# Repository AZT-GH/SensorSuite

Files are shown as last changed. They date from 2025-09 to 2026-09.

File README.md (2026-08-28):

# AZSensorSuite




> [!WARNING]
> This device has been mostly tested, however, problems may arise. Expect changes and please report any inaccuracies or issues.

## Overview
land_export
   
AZSensorSuite (AZSS) is an ultra-low-power, data-acquisition hardware platform designed to be user-programmed for a variety of applications. 

The included example firmware implements a unidirectional object counter and temperature and humidity logger, with BLE implemented for real time updates and data download.

**Interactive Viewer:** View the PCB and schematic entirely in your browser on [KiCanvas](https://kicanvas.org/?repo=https%3A%2F%2Fgithub.com%2FAZT-GH%2FSensorSuite%2Ftree%2Fmain%2Fhardware).

#

**Special thanks to [**PCBWay**](https://www.pcbway.com/) for sponsoring the development of this project.** 

If you're looking for high-quality advanced PCB manufacturing and assembly and great customer support, check them out.

#

### Hardware Features

* **SoC / Connectivity:** Nordic NRF54L15 (via U-Blox Nora B206 module). Supports BLE 6.0, Matter, Thread, Zigbee, and proprietary 2.4GHz communication.
* **ToF Sensor:** ST Microelectronics VL53L4CD. Used for ULP presence detection ([STSW-IMG034](https://www.st.com/en/embedded-software/stsw-img034.html), as low as 154µW) or standard ranging ([STSW-IMG026](https://www.st.com/en/embedded-software/stsw-img026.html)).
* **Environmental Sensor:** Sensirion SHT30 for ambient temperature and humidity readings.
* **Power:** Powered by a CR2032 coin cell, converted to 2.8V. The entire system is ultra-low power (e.g., ~400µA in the human detection example).

> [!TIP]
> The VL53L4CD and SHT30 are both members of pin-compatible sensor families. They can easily be replaced to meet specific project requirements or to navigate supply chain shortages.

## Example Quickstart Guide

### Requirements
* NRF54L15DK (highly recommended) or another SWD debugger.
* SensorSuite PCB and TC2030-IDC-NL cable.
    * *Alternatively:* NRF54L15DK with sensor breakouts.
* [nRF Connect SDK v3.1.1](https://developer.nordicsemi.com/nRF_Connect_SDK/doc/latest/nrf/index.html) via nRF Connect for VS Code.
* Python 3.7 or higher.

### Build and Flash Process
* If working with the development kit, skip step 5 and in `firmware/prj.conf` set `CONFIG_APP_BOARD_IS_PROD=n`.
1.  Clone the repository to a path that contains **no spaces** (e.g., `/projects/sensor_suite` is good; `/projects/sensor suite/` will cause build errors).
2.  Open the application in nRF Connect and navigate to the `firmware` subfolder.
3.  Create a new build configuration:
    * **Target:** `nrf54l15dk/nrf54l15/cpuapp/ns`
    * **Base configuration:** `prj.conf`
    * **Base devicetree overlay:** `boards/nrf54l15dk_nrf54l15_cpuapp_ns.overlay`
    * Select your desired build optimization.
4.  Click **Generate and Build**.
5.  Connect the TC2030-IDC-NL to the DK. The DK will automatically detect it and change the target to the connected custom PCB.
6.  Press **Flash and Erase**. (You may flash without erase after the first flash)
* If a module is being flashed for the first time, it may have memory protections enabled. Click `Yes` in the pop-up to allow recovery.

error

## PCB Ordering Guide

| I used [**PCBWay**](https://www.pcbway.com/) for PCB fabrication as they offer reliable quality, competitive pricing, and quick turnaround, even with the nonstandard specs required by this project. |
|---|
### 1. Clone and Open the Project
1. Clone the repository to your local machine.
2. Open `azss.kicad_pro` in **KiCad 9** or newer.
3. *(Optional)* Make any custom modifications needed for your project.

### 2. Run Design Rules Check (DRC)
Run the DRC in KiCad to verify your layout.

> [!NOTE]
> You can safely ignore the following DRC error:
> 
> KiCad DRC Error

### 3. Export Gerber & Drill Files
1. Open the PCB Editor.
2. Go to **File → Fabrication Outputs → Gerbers (.gbr)**.
3. Choose or create a dedicated output directory (e.g., `fabrication/`).
4. Click **Plot**.
5. Click **Generate Drill Files**, keep default options, and click **Generate**.
6. Compress the contents of your output directory into a single **`.zip`** file.

### 4. Upload to PCBWay
1. Go to the [PCBWay Quick Order Page](https://www.pcbway.com/QuickOrderOnline.aspx).
2. Upload your `.zip` file.
3. Inspect your layout using the online **Gerber Viewer** to verify the gerber exported correctly.

### 5. Configure PCB Parameters
Set the board parameters to match the project requirements:

* **Layers:** Select **4 Layers**.

<details>
<summary><b>Click to view 4-Layer Stackup Configuration</b></summary>
<br>
Layer Stackup Configuration

</details>

* **Required PCB Specifications:**
  * **Min Track / Spacing:** `4/4mil`
  * **Min Hole Size:** `0.3mm`
  * **Surface Finish:** `Immersion Gold (ENIG)`
  * **Via Process:** `Plugged vias with solder mask`

### 6. Add Assembly / Stencil & Checkout
1. **Stencil / Assembly:** Add an **SMD Stencil** if hand-assembling, or select PCBWay's **Assembly Service** if you want them professionally assembled.
2. Click **Save to Cart**.
3. Wait for PCBWay's order review to complete, typically within an hour.
4. Proceed to checkout, pay, and wait for your boards!
   
## Release Notes

v1.0.0 - 17/04/26 - Initial release with all core features implemented

## License

Copyright © 2026 Adam Zembrzuski. 

This project is licensed under the TAPR Open Hardware License ([www.tapr.org/OHL](https://www.tapr.org/OHL)).

A full copy of the license is available in the `license.txt` file in this repository.

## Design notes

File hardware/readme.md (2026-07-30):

## Hardware

This folder contains all hardware design files and documentation.

**Interactive Viewer:** View the PCB and schematic entirely in your browser on [KiCanvas](https://kicanvas.org/?repo=https%3A%2F%2Fgithub.com%2FAZT-GH%2FSensorSuite%2Ftree%2Fmain%2Fhardware).
##
### PCB Fabrication

Special thanks to [**PCBWay**](https://www.pcbway.com/) for sponsoring the development of this project.

| Parameter | Value |
|---|---|
| Layers | 4 |
| Board thickness | 1.6mm |
| Surface finish | 2µ" ENIG with *(preferably)* selective hardened gold for the battery contact |
| Min hole size | 0.3mm |
| Min track spacing | 4mils |
| Via process | See below |

- Due to the nature of the vias sitting on the battery contact, copper/resin filled vias are highly encouraged.

- LPI filled or tented vias will work for at least ~50 insertions.

- **Untented vias are unsuitable and will cause catastrophic failure if a battery is inserted.**

### Stencil

Electropolished stencils are preferred over 
laser-cut for cleaner paste release on the LGA pads of the Nora B206.

### Assembly Notes

- The U-Blox Nora B206 and ST VL53L4CD are LGA components and **must be reflow soldered**. 
  Hand soldering is not possible.

### Schematic Notes

- **R1** should be replaced to a suitable value for current measurement instead of 0 ohms.
- Several components are marked DNP. These should only be populated if you have a specific reason to do so.

> [!TIP]
> If the SHT3x is not required, C11 and U4 can be DNP'd, and in the example firmware, `CONFIG_APP_SHT_ENABLE` should be set to `n`in `firmware/prj.conf`.

### Test Points

Test point layout is visible below and is consistent with the schematic.

test points

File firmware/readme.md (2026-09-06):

## Firmware

This folder contains all firmware source files and documentation. The latest firmware (release v1.0.0)
has been verified working on PCB V1.12 (all functions).

For build and flash instructions, see the 
[main README](../README.md#example-quickstart-guide).
##

### Implementation Status

| Feature | Status |
|---|---|
| VL53L4CD ToF detection | Complete |
| SHT30 temperature / humidity | Complete |
| BLE service | Largely complete |
| NVM storage | Complete |
| Dynamic ToF interval | Complete |
| SAADC VCC monitoring | Planned |

### BLE Service

The device exposes a custom BLE service with the following characteristics:

Service UUID : `229a0001-ad33-4a06-9bce-c34201743655`

| Characteristic | UUID | Properties | Encryption | Description |
|---|---|---|---|---|
| Count | `229a0002-ad33-4a06-9bce-c34201743655` | Notify, Read | None | Returns detected object count |
| Temperature | `229a0003-ad33-4a06-9bce-c34201743655` | Notify, Read | None | Returns last good temperature |
| Humidity | `229a0004-ad33-4a06-9bce-c34201743655` | Notify, Read | None | Returns last good humidity |
| Bulk Download | `229a0005-ad33-4a06-9bce-c34201743655` | Notify | Level 2 | Used to download timestamp log |
| Current Timestamp | `229a0006-ad33-4a06-9bce-c34201743655` | Read | None | Returns current timestamp |
| Base Timestamp | `229a0007-ad33-4a06-9bce-c34201743655` | Write, Read | Level 2 | Used to write base timestamp |
| Command | `229a0008-ad33-4a06-9bce-c34201743655` | Write, Read | Level 2 | Used to call one of many commands |

### 'Command' Commands

| Command | Hex | Return | Description |
|---|---|---|---|
| Connection Interval 20ms | `0x00` | none | Sets new connection interval |
| Connection Interval 100ms | `0x01` | none | Sets new connection interval |
| Connection Interval 512ms | `0x02` | none | Sets new connection interval |
| Connection Interval 1024ms | `0x03` | none | Sets new connection interval |
| Download Start | `0x10` | 0 on success | Starts timestamp download notifications |
| Download Stop | `0x11` | 0 on success | Stops timestamp download notifications |
| Storage Clear | `0x13` | 0 on success | Clears NVM, including bonding, configuration, and logs |
| Firmware Version | `0x20` |int (eg `12` for V1.2)| Returns FW Version |
| Active Period 08-16 | `0x30` |  0 on success | Sets the device to only detect <sup>¶</sup> between 08:00 and 16:00 |
| Active Period 08-18 | `0x31` |  0 on success | Sets the device to only detect between 08:00 and 18:00 |
| Active Period 09-21 | `0x32` |  0 on success | Sets the device to only detect between 09:00 and 21:00 |
| Active Period 00-24 | `0x33` | 0 on success | Sets the device to detect irrespective of time (not date) |
| Inactive Weekend | `0x34` | 0 on success | Sets the device to not detect during the weekend |
| Active Weekend | `0x35` | 0 on success | Sets the device to detect during the weekend |

*¶ Detect refers to human/object detection, ambient detection is still carried out*

### Data Collection
The device only collects timestamp logs if it is within the active period, definable via the 0x3- commands. The selected active period is stored in NVM.

Ambient logs are collected regardless of the system state (if the SHT3x is enabled in `prj.conf`).

### Logging

*Logging described in this section is independent of sensor logging*

RTT logging is enableable in `prj.conf`. Connect via the nRF Connect for Desktop 
terminal or a J-Link RTT Viewer.

### Kconfig Options
All Kconfig options can be adjusted in `firmware/prj.conf`. If changes are not being applied, ensure `prj.conf` is included in the build config.

#### System Level
<details>
<summary>For lowest current consumption disable all logging, this will reduce current consumption by roughly 200μA</summary>

```
CONFIG_USE_SEGGER_RTT=n
CONFIG_SERIAL=n

CONFIG_LOG=n
CONFIG_LOG_BACKEND_RTT=n
CONFIG_LOG_BACKEND_UART=n

CONFIG_PRINTK=n
CONFIG_BOOT_BANNER=n

CONFIG_UART_CONSOLE=n
CONFIG_RTT_CONSOLE=n
```

</details>
<details>
<summary>Bluetooth options such as device name and default connection interval are available to be defined statically.</summary>
  
```
CONFIG_BT_DEVICE_NAME="AZSensorSuite-001"
```
</details>

#### Application Level

Application specific Kconfig option descriptions can be viewed in the visual kconfig editor, in the nRF  Connect SDK. Below are some key options.

- `CONFIG_APP_VL53_DETECTION_INTERVAL_MS` - Inter-measurement period for the VL53L4CD ToF sensor in milliseconds. Must be a multiple of ten.

- `CONFIG_APP_CONSEC_DETECT_FILTER` - Require multiple consecutive detections before logging an event. Should be paired with a lowered detection interval.

- `CONFIG_APP_SHT_ENABLE` - Disable functions related to the SHT3x, notably it still *remains powered* even in this mode.

- `CONFIG_APP_LOG_FULL_STRATEGY` - Determines if logs are overwritten when full or if writing stops.

- `CONFIG_APP_BOARD_IS_PROD` - Should be set to `n` if building for the nRF5454L15-DK.

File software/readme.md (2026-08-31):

## Software

This folder contains the host-side Python client for communicating with
AZSensorSuite over BLE.

**ML functionality has not been implemented yet, and will not be implemented in the forseeable future.**

> [!WARNING]
> This client was written quickly to test the firmware and is due for a rewrite. Please expect and report bugs.

*Python 3.7 or higher is required.*

##

### Overview

The intended data flow is:
```
Device (BLE) → azss_client.py → csvs/ → azss_train.py → model → azss_infer.py → prediction
```

The BLE client is currently implemented. Model training and infer scripts 
are in progress.

## azss_client.py
### Setup
```bash
pip install -r requirements.txt
```

> [!NOTE]
> On macOS, Bleak exposes CoreBluetooth UUIDs rather than MAC addresses. 
> When prompted for a Bluetooth address, use the UUID string instead.

### Usage
```bash
python azss_client.py
```

The client runs as an interactive shell. Type `help` for a list of commands 
or `exit` to quit.

### Commands

| Command | Requires Connection | Description |
|---|---|---|
| `scan` | No | Scan for nearby BLE devices |
| `connect` | No | Connect to a device by Bluetooth address |
| `disconnect` | No | Disconnect from the current device |
| `unpair` | No | Unpair the current device |
| `read uuid` | Yes | Read a characteristic by UUID |
| `read count` | Yes | Read detected object count since last initialisation |
| `read temp` | Yes | Read temperature (returns °C, °F, and K) |
| `read humidity` | Yes | Read relative humidity |
| `read time` | Yes | Read the current device timestamp in milliseconds |
| `write` | Yes | Send a raw hex command byte to the Command characteristic |
| `write time` | Yes | Sync device base timestamp to system time |
| `write time custom` | Yes | Write a custom base timestamp in milliseconds |
| `download` | Yes | Download the full timestamp and ambient log |

### Download Output

Data is written to the `csvs/` folder, created automatically if it does not exist.

**`stamps.csv`** — ToF event log

| Column | Description |
|---|---|
| `row` | Row index |
| `seq` | BLE packet sequence number |
| `delta_i32` | Time delta from previous event in seconds |
| `cumulative_i64` | Cumulative elapsed seconds since base timestamp |
| `real_i64` | Absolute Unix timestamp in seconds |

**`ambient.csv`** — Temperature and humidity log (sampled every 15 minutes)

| Column | Description |
|---|---|
| `row` | Row index |
| `seq` | BLE packet sequence number |
| `temp_i8` | Temperature in °C |
| `humidity_u8` | Relative humidity as a percentage |
| `real_i64` | Absolute Unix timestamp in seconds |

## azss_train.py

## azss_infer.py

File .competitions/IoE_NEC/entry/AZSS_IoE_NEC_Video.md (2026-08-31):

# Demo Video

[Watch on YouTube](https://www.youtube.com/watch?v=mV7OCPhzP5s)

thumbnail

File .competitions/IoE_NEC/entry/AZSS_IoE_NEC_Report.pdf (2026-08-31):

## An Ultra-Low-Power IoT ToF Sensor Node

Adam Zembrzuski, Banbridge Academy, Banbridge, Down, BT32 4AQ

### 1 - Introduction

My GCSE Technology project was a bin-mounted object counter, built around an IR LED, photodiode and 9V battery. It worked but the prototype was fragile, bulky and power-hungry, unsuitable for commercial production. This project is the result of wanting to develop the concept properly. An almost product-grade redesign that also served as my foundation to learning a modern Bluetooth SoC platform. The project was primarily funded by my Arkwright Scholarship, with PCB manufacturing sponsored by PCBWay. Development began in August 2025, with v1.0 releasing during April 2026.

The project is called AZ Sensor Suite (AZSS).

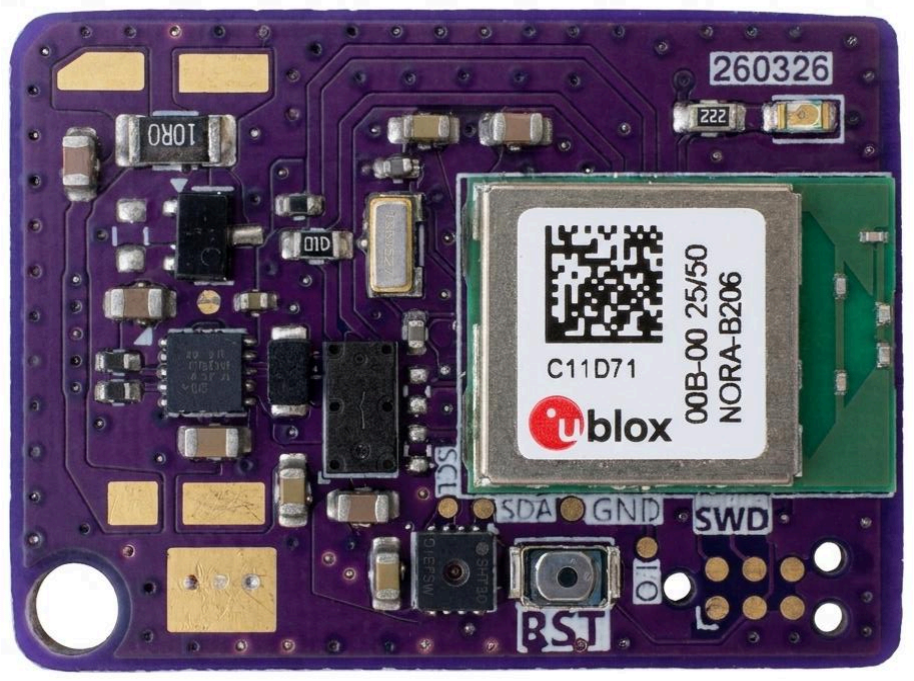
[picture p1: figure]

Fig 1.0.0.1 - Assembled PCB v1.11 (30.2 x 22.1 mm)

### 2 - The Problem to be Solved

There does not exist a low cost (Spec 2.1), small form factor (Spec 2.2), ultra-low power (Spec 2.3) , IoT enabled (Spec 2.4), unified development platform for distance-measurement and presence detection applications. This means it is difficult to leverage ToF sensing in heavily constrained environments.

Example applications include:

- Fill-level monitoring for storage containers
- Presence-triggered network input (e.g., for smart home automation)
- Unidirectional throughput and object counting
- Simple tamper detection

The device should operate autonomously via direct wireless connectivity or be able to integrate into broader smart-home or industrial networks (Spec 2.5), and should be highly accurate (Spec 2.6) so that obtained data is reliable and usable for analysis.

Paper produced for the Institution of Electronics

### 3 - Research

3.1 - Customer-base and usage model
The project is primarily an open-hardware platform, with user responsibility for their own application firmware. To improve ease of development, a reference firmware implementation is provided for unidirectional object counting with Bluetooth connectivity.

The project caters to two market segments

- Conventional purchase model - The user programs the device independently. These users retain total control over the project. They prioritise reliability, repairability and ease of programming. (Spec 3.1)
- Hardware-as-a-Service (HaaS) model - The user receives a turnkey solution that does not require custom firmware development. Under this rental model, the user does not have to manage installation and maintenance, over a typical two-year lifecycle. (Spec 3.2)

This report will focus on users that fall under the conventional purchase model.

3.2 - Market solutions
As established in the problem analysis, no commercial solutions currently address this specific niche. The closest market analogues are official sensor evaluation breakout boards. While these manufacturer-provided modules break out the Time-of-Flight (ToF) sensor pins for initial firmware validation, they carry significant limitations for deployment:
- Lack of integration - They only feature the sensor, essential passives and a pin header. They lack onboard processing, power management, or wireless connectivity.
- Poor form factor - They require external processors to be connected via jumper wires, making them bulky and structurally unsuitable for permanent and/or mobile applications.
- High unit cost - They are produced in low volumes for development purposes, hence have a premium cost. A single breakout board costs more than the total BoM cost of the AZSS.

Breakout boards were used extensively during the initial phases of this project to validate firmware and characterise the sensor. However, this development process highlighted their limitations; the resulting breadboard setups were highly fragile, expensive, and unsuitable for any deployment.

3.3 - Hardware research

3.3.1 - Power Source and Topology

To maximise its deployability, the project requires an ultra small form factor, which implies an ultra-low-power budget. A primary CR2032 coin cell was selected over secondary lithium alternatives due to widespread availability and the elimination of space-demanding charging circuitry.

A CR2032 cell features a nominal voltage of 3.0 V with a usable range of roughly 2.0 V to 3.2 V. Due to the system's target operating voltage being 2.8 V, a buck-boost topology was required to efficiently utilise the full voltage range. The TI TPS63900 was chosen as a buck-boost converter with low quiescent current of 75 nA and high theoretical efficiency of approximately 88% under coin cell power.

Adam Zembrzuski, Banbridge Academy, Banbridge | Page 2

3.3.2 - Distance Sensing Technology

Two ToF technologies were evaluated:

Selection Criteria | Infrared (IR) Laser ToF | Ultrasonic ToF
Key Advantages | ● Low cost ● Simple API integration ● Narrow FoV without optics | ● Lower active current draw ● Optical material agnosticity ● Higher sampling rate
Key Limitations | ● Higher current draw ● Lower maximum operating range | ● High component cost ● Requires mechanical horn to narrow FoV

Fig 3.3.2.1 -
Comparison of infrared and ultrasonic ToF sensing

IR laser sensing was selected to minimise hardware complexity and cost per unit. Specifically, the STMicroelectronics VL53L4CD was chosen as it includes an autonomous, ultra-low-power presence detection API that reduces current consumption to as little as 55 μA [1], and operates on a relatively low supply voltage of 2.8 V.

3.3.3 - System on Chip (SoC) Selection

The core SoC architecture requires capabilities to use a wireless protocol capable of integrating with smart-home networks without exceeding the strict power budget imposed by a coin cell. Wi-Fi connectivity was ruled out immediately due to its high peak current, which would rapidly deplete or brown out a CR2032 cell. Consequently, low-power personal wireless area network (LP-WPAN) protocols, specifically Bluetooth Low Energy (BLE), Thread, and Zigbee, were identified as viable IoT protocols for home and network integration.

To fulfil these requirements, the Nordic Semiconductor nRF54L15 was selected. As a state of the art SoC manufactured on TSMC’s 22ULL (22 nm, ultra low leakage) process node, it delivers double the processing performance and triple the energy efficiency of previous generation hardware. It supports multi-protocol stacks, features an ultra low sleep current (as low as 0.7 μA [2]), and offers a robust SDK ecosystem, with free training material provided by Nordic Semiconductor.

Crucially, its operating voltage matches the sensor rail, enabling the entire system to run off a single power supply and eliminating the space, cost, and efficiency losses of logic-level translation. I decided to use an FCC/CE-certified module over a bare SoC as it integrated the antenna and other essential passives.

This minimised RF layout complexity and greatly reduces RF certification costs if the device is to be commercially manufactured. The benefit of already having certain core passives also reduces the total number of unique parts in the BoM. However the limitations of this are that the total cost for a module is higher than the cost of the bare SoC and passives, and that a smaller solution footprint can be designed if a module is not used.

3.3.4 - Auxiliary Sensor Selection

To add environmental telemetry, a low-power, low-cost Sensirion SHT30 temperature and humidity sensor was integrated onto a shared I

2C bus. Importantly, both the VL53L4CD and the SHT30 share pin-compatible footprints with other sensors in their respective manufacturer portfolios. This design choice allows the platform's hardware configuration to be modified for alternative use cases (e.g., extended ranging depth or temperature accuracy) purely via a component swap and a firmware update, without requiring a PCB redesign.

3.4 - Firmware research

3.4.1 - Operating System Selection

To match the requirements of sensor monitoring and multi-protocol wireless communication, a real-time operating system (RTOS) was chosen over a traditional bare-metal super-loop architecture. While a bare metal approach minimises overhead, executing network tasks alongside sensor interactions and NVM events introduces timing risks and blocking conditions.

Zephyr RTOS was chosen as the firmware platform as it features industry-grade networking stacks that are natively supported by nRF Connect SDK in the VS Code IDE. Zephyr is the standard for firmware for Nordic Semiconductor based processors hence there is a wealth of examples available for users to adapt for their application firmware.

3.4.2 - Sensor API and Power Architecture

The implementation required selecting from one of two manufacturer-provided APIs for the VL53L4CD sensor.

- STSW-IMG026 (Ranging Driver) - Provides comprehensive distance data over an I

2C bus.
Relies on processor polling, which prevents the processor from entering low-power sleep states for extended periods, leading to increased baseline current consumption.
- STSW-IMG034 (Presence Driver) - Functions autonomously by executing threshold checks directly on the sensor. Operates on an interrupt-driven basis, asserting a hardware interrupt pin only when a target crosses a configured detection threshold. An I

2C write is still required to deassert the interrupt pin.

To maximise battery longevity, the STSW-IMG034 API was selected. This choice permitted a highly efficient, event-driven firmware architecture. The nRF54L15 remains in an ultra-low-power "System ON" sleep state, consuming 2.9 μA of current (more than the 0.7 μA floor due to full memory retention), and only wakes to process data when triggered by the sensor's hardware interrupt.

3.5 - Reference Firmware and Development Methodology

3.5.1 - Reference Firmware Architecture

To demonstrate the platform's capabilities and provide a foundation for custom development, a reference firmware implementation was developed for unidirectional object counting with environmental logging.

The application utilises an event-driven architecture to capture, queue and secure data:

- Autonomous Presence Interrupts - The VL53L4CD is configured using the STSW-IMG034 API, allowing the nRF54L15 to remain in ultra-low-power ‘System ON’ sleep state and wake up solely to process events or perform periodic logging (if configured).
- Buffered Storage Architecture - To ensure data persistence across power faults, events are queued in a RAM ring buffer and flushed to a 400 KB NVM partition periodically. Storing events as 32-bit timestamps, providing a theoretical capacity of over 50,000 entries (the timestamps are not strictly 32-bit due to filesystem overhead). Because the nRF54L15 utilises Resistive RAM (RRAM) for NVM, wear levelling is not necessary.
- Periodic Environmental Telemetry - The SHT30 temperature and humidity sensor is managed via a low-frequency polling schedule on the shared I

2C bus. Its logs are directly committed to the NVM.

This reference design serves as a functional validation example that showcases all of the primary hardware subsystems, including the BLE stack, NVM storage, I

2C bus, and low-power hardware interrupts under realistic constraints.

3.5.2 - Hardware / Firmware Co-design Methodology

To minimise project schedule risks and ensure rapid hardware bring-up, a hardware/software co-design methodology was employed. Firmware development was decoupled from physical PCB fabrication by implementing the firmware concurrently on an off-the-shelf Nordic Semiconductor development kit (DK). The development kit contains a SEGGER J-Link OB debugger that programs the nRF54L15 SoC on the DK and can be connected by a cable to program a custom PCB. It also supports breakpoint debugging allowing for thread activity and stack usage to be analysed.

This parallel workflow allowed the BLE stack, low-power state transitions, and sensor drivers to be fully validated and debugged in advance. Consequently, when the PCB prototype was assembled, a usable firmware version could be almost immediately flashed, reducing integration debugging to hardware-specific routing and definitions.

### 4 - Design and Build

4.1 - Schematic Design
Unlike the physical PCB layout stage, where Electronic Design Automation software actively flags issues, the schematic entry phase relies entirely on manual design verification. Any electrical routing or footprint mapping errors introduced here are silent and pass automated checks unnoticed.

This risk materialised during the initial design cycle: a schematic symbol adapted for the PMOS-based reverse polarity protection circuit featured non-standard pin numbering that did not match its physical footprint, resulting in a complete power delivery failure on the prototype. This highlighted the necessity of rigorous, multi-point footprint verification prior to fabrication. The development of the schematic proceeded through several distinct stages:

4.1.1 - Power Delivery and Diagnostics

The primary power stage was modelled using Texas Instruments’ WEBENCH suite as an initial baseline. To elevate this reference design for custom debugging and Design for Testability (DFT), several additions were integrated as illustrated in Fig 4.1.1.1.

- A PMOS-based reverse polarity protection circuit to safeguard the board during battery swapping.
- A series shunt resistor for optional, high-precision power measurements.
- Dedicated diagnostic test points for the battery voltage (+BATT), system voltage (+2V8), ground (GND), and the shunt’s high/low nodes.
- Zero-ohm current limit configuration resistor (instead of a direct connection to ground) to allow adjustment of the current limit if necessary.

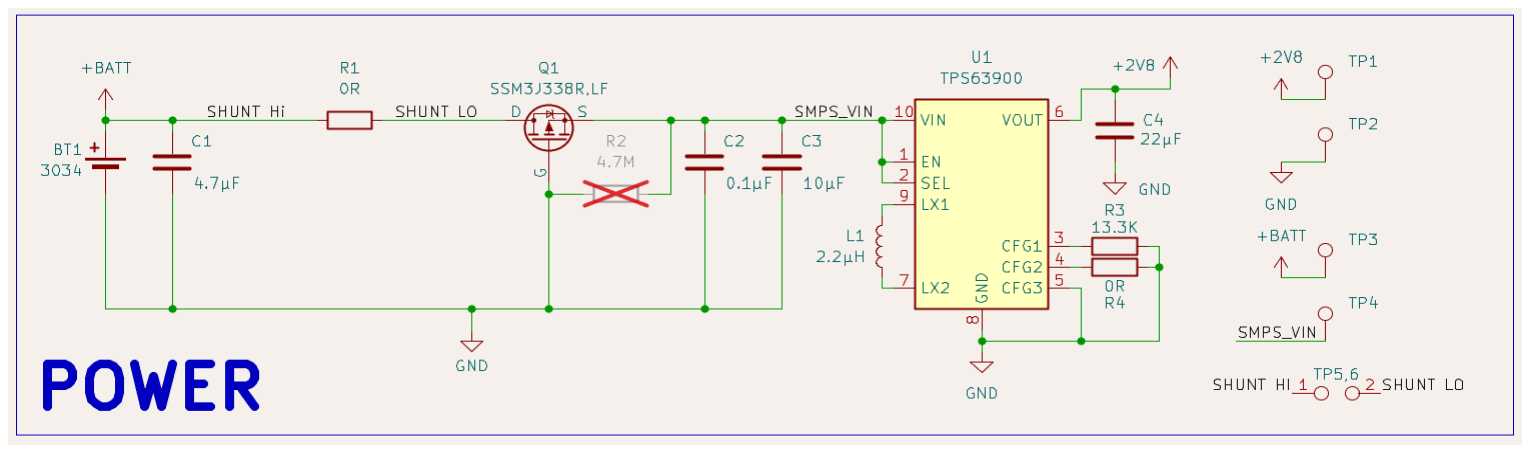
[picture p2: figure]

Fig 4.1.1.1 - Excerpt of schematic showing power section

4.1.2 - SoC Integration and Custom Footprint Generation

At this point the u-blox NORA-B206 module was selected because it incorporates the highest-memory variant of the nRF54L family and is available from reputable distributors. As the nRF54 family was released relatively recently, community footprint libraries were practically non-existent.

Hence, a custom schematic symbol and high-density Land Grid Array (LGA) footprint had to be drawn completely from scratch, cross-referencing the manufacturer’s datasheet dimensions. Using this validated symbol, the module's general-purpose I/O pins were mapped to route the shared I

2C
bus for the sensors, and the GPIO (GPIO1 and XSHUT) pins of the VL53L4CD could be connected.

4.1.3 - Connectorless Programming Interface

To optimise the Bill of Materials (BoM), a component-free programming header footprint was selected. Rather than soldering a physical, multi-pin header to the board, the programming interface consists of exposed gold pogo-pin target pads aligned with Non-Plated Through Holes (NPTH). This mechanical choice eliminated an assembly component, saving physical board space and reducing unit weight, cost, and complexity.

4.2 - PCB Design

4.2.1 - Stackup and Mechanical Constraints

The transition of the schematic to a routing layout introduced substantial geometric and signal integrity constraints. To manage the dense routing of the high-pin-count LGA package of the SoC and maintain signal integrity, a four-layer board stackup was chosen:

- Layer 1 (Top) - Component placement, signal routing and some power routing.
- Layer 2 (Inner) - Solid ground plane for low impedance return paths.
- Layer 3 (Inner) - Power plane including very minimal signal routing.
- Layer 4 (Bottom) - Large negative battery contact pad and mechanical ground.

To reduce fabrication costs, Via-in-Pad Plated Over (VIPPO) technology was avoided. However, the physical dimensions of the board were strictly bound by the battery holder footprint. The selected solution, a low-cost, minimal-footprint metal retainer style holder, solders directly to the PCB to connect the positive terminal, while the negative cell terminal is pressed directly against a large exposed gold-plated (ENIG) pad on the bottom layer. Because of this large contact area, trace routing on the bottom layer was highly restricted.

4.2.2 - Battery Interface Failure Analysis and Mitigation

Due to cost-saving measures during PCB manufacturing, vias routed through the bottom-layer battery contact zone were tented with solder mask rather than being plugged/filled with epoxy. Because tented vias are physically raised and less durable than filled vias, they proved highly vulnerable to
mechanical stress. | Fig 4.2.2.1 - Rear PCB view without holder

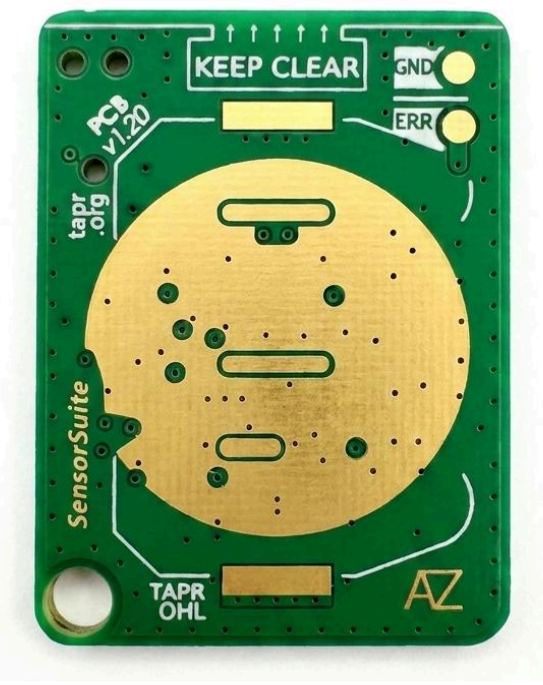
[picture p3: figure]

During early testing, the sharp metallic edge of the coin-cell
battery casing abraded the PCB surface during insertion. After
approximately 100 battery insertions across two prototypes,
this continuous mechanical abrasion scraped away the thin solder mask, causing the 2.8 V power net to short to ground whenever the battery was installed.

To resolve this issue on the immediate hardware prototypes, a manual retrofit was applied by reflowing a bead of solder directly onto the centre ground contact. This localised solder dome physically elevated the battery case by roughly a millimetre. This clearance successfully lifted the sharp outer edge of the battery casing away from the vulnerable 2.8 V vias, minimising future abrasion and temporarily restoring function to the broken prototypes.

To translate this physical workaround into a clean, repeatable manufacturing step, the solder and paste masks were revised to create PCB v1.12, from which I later designed v1.20. As shown in Figure 4.2.2.1, three dedicated, solderable spacer pads (the grey pill-shaped landing pads) were integrated directly into the central gold contact zone. During assembly, if necessary, solder can be cleanly reflowed onto these pads to create precise, solid mechanical shims that raise the cell safely above the surrounding board plane.

4.2.3 - Layout Optimisation and Noise Mitigation

The top-layer layout was optimised to balance noise immunity and signal integrity. To suppress electromagnetic interference from the Switch-Mode Power Supply (SMPS), switching loop areas were minimised. Similarly, I

2C traces were routed short and direct to minimise parasitic bus capacitance, keeping rise times fast enough to run the bus reliably at 100 kHz using only the weak internal SoC pull-ups. Finally, copper pours and ground stitching vias minimised trace resistance and were used to reduce return path impedance.

4.3 - PCB Assembly
The high-density layout made hand soldering hard / impossible due to 0402 (1.0 mm x 0.5 mm) passives and the u-blox NORA-B206 LGA package, which features hidden pads with a 0.9 mm pitch. Consequently, a surface-mount reflow process was utilised, employing an electropolished stencil, 137°C bismuth-based solder paste, and a laboratory hot plate. A custom alignment jig was created to overcome initial deposition inconsistencies, securing a relatively repeatable (for my use case) paste-application success rate over 70%. To ensure hardware longevity and supply-chain resilience, all components were sourced from reputable distributors, filtering out any Not Recommended for New Designs (NRND) or obsolete parts.

4.4 - Firmware Design

The firmware was developed in C using the Zephyr RTOS within the Nordic nRF Connect SDK, compiling to approximately 140 kB of NVM and 55 kB of RAM. The architecture decouples the main state machine loop in main.c from peripheral drivers managed via modular service headers.

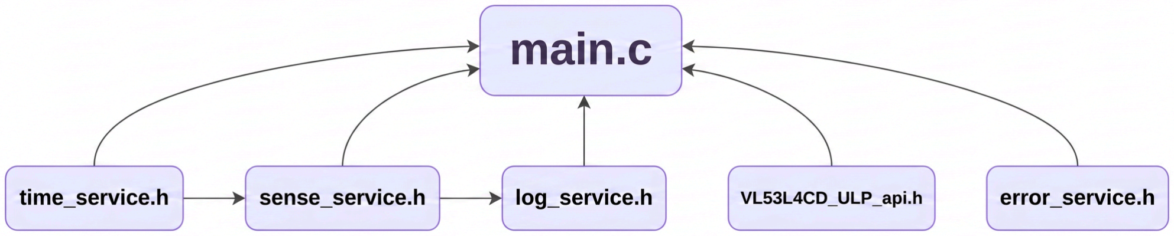
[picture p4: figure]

Fig 4.4.0.1 – Modular firmware structure diagram, arrows indicate consumed service headers

4.4.1 - BLE Profile and Custom GATT Service

To optimise power consumption, the device functions as a Bluetooth Low Energy (BLE) GATT Server that limits advertising to two minutes post-reset or after covering the sensor for 9.6 seconds (configurable via Kconfig flags). The custom GATT service exposes encrypted read characteristics (count, temperature, humidity, timestamp), write characteristics (base_timestamp for time synchronisation, command for OTA filesystem control), and a notify characteristic (download) to stream logged data using a custom protocol.

4.4.2 - State Machine and Adaptive Ranging

The core system loop is governed by a state machine optimised for minimal CPU active time. The device enters a low-power sleep state during user-defined "inactive hours" to conserve energy. When active, the sensor ranging rate dynamically scales from a standby 2 Hz (500 ms interval) to an active 10 Hz (100 ms interval) upon detecting an object, capturing high-density events for a programmable duration before returning to standby. An optional debouncing filter can also be enabled to require the target to remain in the ToF’s field-of-view for more than one detection. This helps increase consistency near the configured detection range at the expense of reducing the effective ranging rate by a factor of the minimum number of consecutive detections for a valid reading, n.

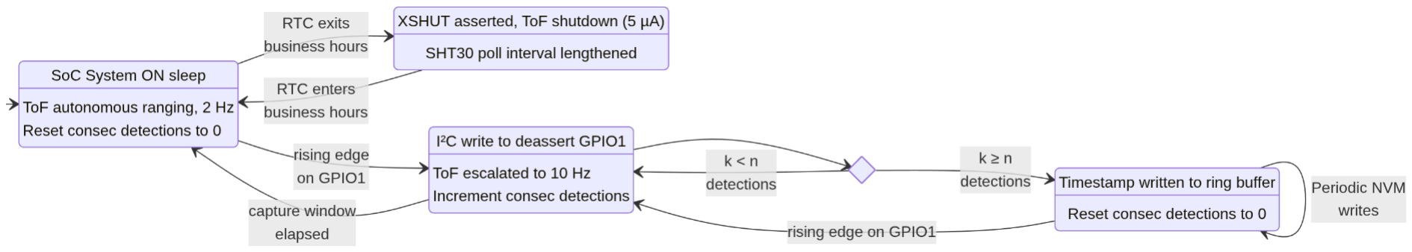
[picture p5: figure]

Fig 4.4.2.1 – System state machine. k = consecutive detection count; n = user-configured debounce threshold (n = 1 disables filtering)

### 5 - Evaluation of Final Product

To assess the physical viability of the prototype, the assembled hardware was validated and evaluated against the key technical and design constraints defined in the initial specification.

5.1 - Performance Testing
Validation focused on characterising the physical trade-offs of the Time-of-Flight (ToF) sensor. Under default firmware settings, the system achieves an effective detection range of 600 mm for a white paper target (in ambient light). Because the VL53L4CD allows for dynamic parameter tuning, the active current draw scales directly with the requested ranging distance and frequency. Adjusting these parameters allows the system to trade range for reduced current consumption, as characterised in the curve below, which displays the current consumption of the ToF sensor (not the whole system).

During high-volume data transfer testing, a firmware limitation was identified: the notification based GATT characteristic struggled with packet delivery during larger bulk downloads (m > 150 entries). This throughput issue does not affect real-time object counting or logging. However, it limits retrieval of historical timestamp records over BLE.

As an application-layer issue rather than a hardware fault, this is readily addressable given the platform's open, user-programmable design (Spec 3.1), but remains a target for development.

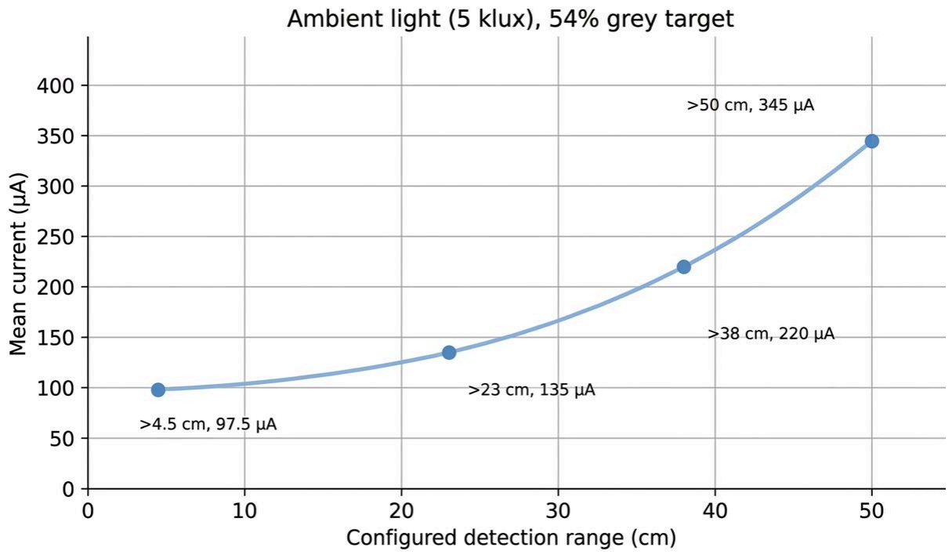
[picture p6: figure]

Fig 5.1.0.1 - VL53L4CD current consumption against range (in isolation)

Spec # | Metric | Target Specification | Achieved Performance
2.1 | Low cost | Total cost per unit under £20. | Over 1ku, cost per unit near £6-£7.
2.2 | Form factor | Solution footprint area under 1000 mm² . | PCB measuring 22.1 mm x 30.2 mm, area approx. 667 mm² .
2.3 | Low power | At least 4 weeks of battery life in continuous operation. | Up to 8 weeks of battery life facilitated by current consumption in the μA range*.
2.4 / 2.5 | Connectivity | Wireless data download up to 10 m (line-of-sight). | Integrated 2.4 GHz radio, line of sight Bluetooth connectivity up to 24 m.
2.6 | Accuracy | Detect at least 90% of the passes of a white target at 0.5m. | 97% accuracy ( white target at 0.5 m) , using default shipped firmware.
3.1 / 3.2 | Usability | Documented open-source repository. | 100% open-source design files [3], including a quickstart guide, labelled renders and multiple README files.

Fig 5.1.0.2 - Requirement Traceability Table

*Shipped firmware current consumption: 470 μA during active hours, ~60 μA during sleep hours. Measured via the §4.1.1 shunt. 150 μA in active hours is achievable with a lowered ranging rate and maximum distance to achieve an estimated 8 weeks of continuous battery-powered operation.

### 6 - Recommendations for Future Work

First, the download section of the example firmware should be rewritten to ensure a complete timestamping example. Secondly, higher resistance pull-up resistors for the VL53L4CD’s GPIO pins should be tested to bring down sleep current closer to a theoretical lower bound of ~25 µA. In the long term, a larger version could be developed to facilitate a rechargeable cell with USB-C charging and an ultrasonic ToF sensor. This would improve detection consistency for optically difficult targets and allow the use of larger cells.

### 7 - Acknowledgements

I would like to thank the Royal Air Force for funding my Arkwright Scholarship which made this project possible, The Smallpeice Trust for administering my Arkwright Scholarship, and PCBWay for reaching out to sponsor free PCB fabrication for the project.

### 8 - References

[1] STMicroelectronics, "VL53L4CD: Time-of-Flight high accuracy proximity sensor," Datasheet, 2021. https://www.st.com/resource/en/datasheet/vl53l4cd.pdf
[2] Nordic Semiconductor, "Current consumption," nRF54L15 Product Specification. https://docs.nordicsemi.com/r/bundle/ps_nrf54l15/page/chapters/current_consumption/doc/current_co nsumption (https://docs.nordicsemi.com/r/bundle/ps_nrf54l15/page/chapters/current_consumption/doc/current_consumption.html-unique_1307930676)
[3] A. Zembrzuski, "AZSensorSuite GitHub Repository," 2026. https://github.com/AdamZembrzuski/SensorSuite

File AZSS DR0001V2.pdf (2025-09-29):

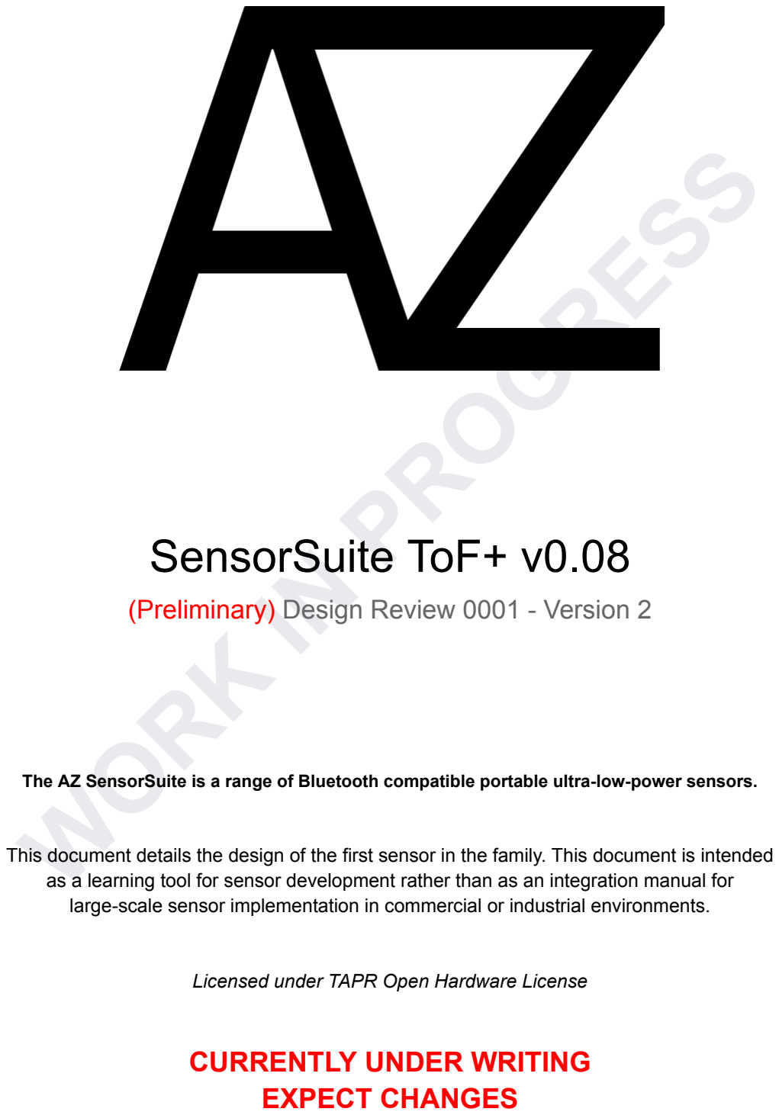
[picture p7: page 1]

# WORK IN PROGRESS

# SensorSuite ToF+ v0.08

## (Preliminary) Design Review 0001 - Version 2

The AZ SensorSuite is a range of Bluetooth compatible portable ultra-low-power sensors.

This document details the design of the first sensor in the family. This document is intended as a learning tool for sensor development rather than as an integration manual for large-scale sensor implementation in commercial or industrial environments.

Licensed under TAPR Open Hardware License

## CURRENTLY UNDER WRITING EXPECT CHANGES

# WORK IN PROGRESS

AZ SensorSuite ToF+ v0.08 DS0001V2

# WORK IN PROGRESS

# CONTENTS

CONTENTS | 1
CHANGELOG | 2
ABBREVIATIONS | 2
Introduction | 3
Context | 4
Design Intent and Specification | 7
ELECTRICAL SPECIFICATION | 7
MECHANICAL SPECIFICATION | 7
Design Review | 8
Schematic Review | 9
CLASS 1 | 9
CLASS 2 | 14
CLASS 3 | 19
PCB Review | 21
CLASS 1 | 21
CLASS 2 | 25

All images that do not have a source listed are owned by me, Adam Zembrzuski.

Contact me at azembrzuski09@gmail.com with queries about image licensing and rights

© 2025 Adam Zembrzuski

YELLOW HIGHLIGHTED TEXT INDICATES THAT IT IS A PLACEHOLDER

TBD-PCB REVIEW
CASE REVIEW
MANUFACTURE REVIEW
CODE REVIEW

# WORK IN PROGRESS

# CHANGELOG

V0 | Initial Commit-COVER, CHANGELOG, ABBREVIATIONS, INTRODUCTION | AZ | 30/08/25
V1 | ADDED SCHEMATIC REVIEW | AZ | 01/09/25
V2 | ADDED PCB REVIEW C1 | AZ | 14/09/25
V3 | ADDED TAPR OHL LICENSE | AZ | 28/09/25

# ABBREVIATIONS

PCB - Printed Circuit Board
GCSE - General Certificate of Secondary Education IR - Infra Red
LED - Light Emitting Diode
(Microchip) PIC - Programmable Interface Controller FDM - Fusion Deposition Modelling
BLE - Bluetooth Low Energy
CE - Conformité Européenne
UKCA - UK Conformity Assessed
LASER - Light Amplification by The Stimulated Emission of Radiation ToF - Time of Flight
PMMA - Polymethyl Methacrylate (Common name Acrylic)
I^2C - Inter Integrated Circuit
BOM - Bill of Materials
API - Application Programming Interface
IC - Integrated Circuit
RH - Relative Humidity
RTC - Real Time Clock
GPIO - General Purpose Input Output µC - Microcontroller
SoC - System on Chip
(Nordic) OPP - Online Power Profiler (Q)SPI - (Quad) Serial Peripheral Interface
USB - Universal Serial Bus
SMPS - Switching Mode Power Supply
SEPIC - Single Ended Primary Inductor Converter EDA - Electronic Design Automation
ADC - Analog to Digital Converter
LGA - Land Grid Array
PTM - Push to Make
BGA - Ball Grid Array
(Inductor) DCR - Direct Current Resistance
PMOS - P Channel MOSFET
MOSFET - Metal Oxide Semiconductor Field Effect Transistor TVS (Diode) - Transient Voltage Suppression
ESD - Electrostatic Discharge
V_RWM - Reverse Breakdown Voltage
VC - Clamping Voltage
EMC - Electromagnetic Compatibility ENIG - Electroless Nickel Immersion Gold MLCC - Multilayer ceramic capacitor
RPP - Reverse Polarity Protection
EMI - Electromagnetic Interference
PDN - Power Delivery Network
DMM - Digital Multimeter

# WORK IN PROGRESS

The TAPR Open Hardware License
Version 1.0 (May 25, 2007)
Copyright 2007 TAPR - http://www.tapr.org/OHL

PREAMBLE

Open Hardware is a thing - a physical artifact, either electrical or mechanical - whose design information is available to, and usable by, the public in a way that allows anyone to make, modify, distribute, and use that thing. In this preface, design information is called "documentation" and things created from it are called "products."

The TAPR Open Hardware License ("OHL") agreement provides a legal framework for Open Hardware projects. It may be used for any kind of product, be it a hammer or a computer motherboard, and is TAPR's contribution to the community; anyone may use the OHL for their Open Hardware project.

Like the GNU General Public License, the OHL is designed to guarantee your freedom to share and to create. It forbids anyone who receives rights under the OHL to deny any other licensee those same rights to copy, modify, and distribute documentation, and to make, use and distribute products based on that documentation.

Unlike the GPL, the OHL is not primarily a copyright license. While copyright protects documentation from unauthorized copying, modification, and distribution, it has little to do with your right to make, distribute,
or use a product based on that documentation. For better or worse, patents play a significant role in those activities. Although it does not prohibit
anyone from patenting inventions embodied in an Open Hardware design, and of course cannot prevent a third party from enforcing their patent rights,
those who benefit from an OHL design may not bring lawsuits claiming that design infringes their patents or other intellectual property.

The OHL addresses unique issues involved in the creation of tangible, physical things, but does not cover software, firmware, or code loaded into programmable devices. A copyright-oriented license such as the GPL better suits these creations.

How can you use the OHL, or a design based upon it? While the terms and conditions below take precedence over this preamble, here is a summary:

* You may modify the documentation and make products based upon it.

* You may use products for any legal purpose without limitation.

* You may distribute unmodified documentation, but you must include the complete package as you received it.

* You may distribute products you make to third parties, if you either include the documentation on which the product is based, or make it available without charge for at least three years to anyone who requests it.

# WORK IN PROGRESS

* You may distribute modified documentation or products based on it, if you:
* License your modifications under the OHL.
* Include those modifications, following the requirements stated below.
* Attempt to send the modified documentation by email to any of the developers who have provided their email address. This is a good faith obligation - if the email fails, you need do nothing more
and may go on with your distribution.

* If you create a design that you want to license under the OHL, you should:
* Include this document in a file named LICENSE (with the appropriate extension) that is included in the documentation package.
* If the file format allows, include a notice like "Licensed under
the TAPR Open Hardware License (www.tapr.org/OHL)" in each documentation file. While not required, you should also include this notice on printed circuit board artwork and the product itself; if space is limited the notice can be shortened or abbreviated.
* Include a copyright notice in each file and on printed circuit board artwork.
* If you wish to be notified of modifications that others may make, include your email address in a file named "CONTRIB.TXT" or something similar.

* Any time the OHL requires you to make documentation available to others, you must include all the materials you received from the upstream licensors. In addition, if you have modified the documentation:
* You must identify the modifications in a text file (preferably
named "CHANGES.TXT") that you include with the documentation. That file must also include a statement like "These modifications are licensed under the TAPR Open Hardware License."
* You must include any new files you created, including any manufacturing files (such as Gerber files) you create in the course of making products.
* You must include both "before" and "after" versions of all files you modified.
* You may include files in proprietary formats, but you must also include open format versions (such as Gerber, ASCII, Postscript, or PDF) if your tools can create them.

TERMS AND CONDITIONS

1. Introduction
1.1 This Agreement governs how you may use, copy, modify, and distribute Documentation, and how you may make, have made, and distribute Products based on that Documentation. As used in this Agreement, to "distribute" Documentation means to directly or indirectly make copies available to a third party, and to "distribute" Products means to directly or indirectly give, loan, sell or otherwise transfer
them to a third party.

1.2 "Documentation" includes:
(a) schematic diagrams;
(b) circuit or circuit board layouts, including Gerber and other data files used for manufacture;

# WORK IN PROGRESS

(c) mechanical drawings, including CAD, CAM, and other data files used for manufacture;
(d) flow charts and descriptive text; and
(e) other explanatory material.
Documentation may be in any tangible or intangible form of expression, including but not limited to computer files in open or proprietary formats and representations on paper, film, or other media.

1.3 "Products" include:
(a) circuit boards, mechanical assemblies, and other physical parts and components;
(b) assembled or partially assembled units (including components and subassemblies); and
(c) parts and components combined into kits intended for assembly by others;
which are based in whole or in part on the Documentation.

1.4 This Agreement applies to any Documentation which contains a notice stating it is subject to the TAPR Open Hardware License, and to all Products based in whole or in part on that Documentation. If Documentation is distributed in an archive (such as a "zip" file) which includes this document, all files in that archive are subject to this Agreement unless they are specifically excluded. Each person who contributes content to the Documentation is referred to in this Agreement as a "Licensor."

1.5 By (a) using, copying, modifying, or distributing the
Documentation, or (b) making or having Products made or distributing them, you accept this Agreement, agree to comply with its terms, and become a "Licensee." Any activity inconsistent with this Agreement will automatically terminate your rights under it (including the immunities from suit granted in Section 2), but the rights of others who have received Documentation, or have obtained Products, directly or indirectly from you will not be affected so long as they fully comply
with it themselves.

1.6 This Agreement does not apply to software, firmware, or code loaded into programmable devices which may be used in conjunction with Documentation or Products. Such software is subject to the license terms established by its copyright holder(s).

2. Patents
2.1 Each Licensor grants you, every other Licensee, and every possessor or user of Products a perpetual, worldwide, and royalty-free immunity from suit under any patent, patent application, or other intellectual property right which he or she controls, to the extent necessary to make, have made, possess, use, and distribute Products. This immunity does not extend to infringement arising from modifications subsequently made by others.

2.2 If you make or have Products made, or distribute Documentation that you have modified, you grant every Licensor, every other Licensee, and every possessor or user of Products a perpetual, worldwide, and royalty-free immunity from suit under any patent, patent application, or other intellectual property right which you control, to the extent necessary to make, have made, possess, use, and distribute Products. This immunity does not extend to infringement arising from modifications subsequently made by others.

# WORK IN PROGRESS

2.3 To avoid doubt, providing Documentation to a third party for the sole purpose of having that party make Products on your behalf is not considered "distribution,"\" and a third party's act of making Products solely on your behalf does not cause that party to grant the immunity described in the preceding paragraph.

2.4 These grants of immunity are a material part of this Agreement, and form a portion of the consideration given by each party to the other. If any court judgment or legal agreement prevents you from granting the immunity required by this Section, your rights under this Agreement will terminate and you may no longer use, copy, modify or distribute the Documentation, or make, have made, or distribute Products.

3. Modifications
You may modify the Documentation, and those modifications will become part of the Documentation. They are subject to this Agreement, as are Products based in whole or in part on them. If you distribute the modified Documentation, or Products based in whole or in part upon it, you must email the modified Documentation in a form compliant with Section 4 to each Licensor who has provided an email address with the Documentation. Attempting to send the email completes your obligations under this Section and you need take no further action if any address fails.
4. Distributing Documentation
4.1 You may distribute unmodified copies of the Documentation in its entirety in any medium, provided that you retain all copyright and other notices (including references to this Agreement) included by each

Licensor, and include an unaltered copy of this Agreement.
4.2 You may distribute modified copies of the Documentation if you comply with all the requirements of the preceding paragraph and:
(a) include a prominent notice in an ASCII or other open format file identifying those elements of the Documentation that you changed, and stating that the modifications are licensed under the terms of this Agreement;
(b) include all new documentation files that you create, as well as both the original and modified versions of each file you change (files may be in your development tool's native file format,
but if reasonably possible, you must also include open format, such as Gerber, ASCII, Postscript, or PDF, versions);
(c) do not change the terms of this Agreement with respect to subsequent licensees; and
(d) if you make or have Products made, include in the Documentation all elements reasonably required to permit others to make Products, including Gerber, CAD/CAM and other files used for manufacture.
5. Making Products
5.1 You may use the Documentation to make or have Products made, provided that each Product retains any notices included by the Licensor (including, but not limited to, copyright notices on circuit boards).

5.2 You may distribute Products you make or have made, provided that you include with each unit a copy of the Documentation in a form consistent with Section 4. Alternatively, you may include either (i) an

# WORK IN PROGRESS

offer valid for at least three years to provide that Documentation, at
no charge other than the reasonable cost of media and postage, to any person who requests it; or (ii) a URL where that Documentation may be downloaded, available for at least three years after you last distribute the Product.
6. NEW LICENSE VERSIONS
TAPR may publish updated versions of the OHL which retain the same general provisions as the present version, but differ in detail to
address new problems or concerns, and carry a distinguishing version number. If the Documentation specifies a version number which applies to it and "any later version", you may choose either that version or any later version published by TAPR. If the Documentation does not specify a version number, you may choose any version ever published by TAPR. TAPR owns the copyright to the OHL, but grants permission to any person to copy, distribute, and use it in unmodified form.
7. WARRANTY AND LIABILITY LIMITATIONS
7.1 THE DOCUMENTATION IS PROVIDED ON AN"AS-IS" BASIS WITHOUT WARRANTY OF ANY KIND, TO THE EXTENT PERMITTED BY APPLICABLE LAW. ALL WARRANTIES, EXPRESS OR IMPLIED, INCLUDING BUT NOT LIMITED TO ANY WARRANTIES OF MERCHANTABILITY, FITNESS FOR A PARTICULAR PURPOSE, AND TITLE, ARE HEREBY EXPRESSLY DISCLAIMED.

7.2 IN NO EVENT UNLESS REQUIRED BY APPLICABLE LAW WILL ANY LICENSOR
BE LIABLE TO YOU OR ANY THIRD PARTY FOR ANY DIRECT, INDIRECT,
INCIDENTAL, CONSEQUENTIAL, PUNITIVE, OR EXEMPLARY DAMAGES ARISING OUT OF THE USE OF, OR INABILITY TO USE, THE DOCUMENTATION OR PRODUCTS, INCLUDING BUT NOT LIMITED TO CLAIMS OF INTELLECTUAL PROPERTY INFRINGEMENT OR LOSS OF DATA, EVEN IF THAT PARTY HAS BEEN ADVISED OF THE POSSIBILITY OF SUCH DAMAGES.

7.3 You agree that the foregoing limitations are reasonable due to
the non-financial nature of the transaction represented by this
Agreement, and acknowledge that were it not for these limitations, the Licensor(s) would not be willing to make the Documentation available to you.

7.4 You agree to defend, indemnify, and hold each Licensor harmless from any claim brought by a third party alleging any defect in the design, manufacture, or operation of any Product which you make, have made, or distribute pursuant to this Agreement.

# Introduction

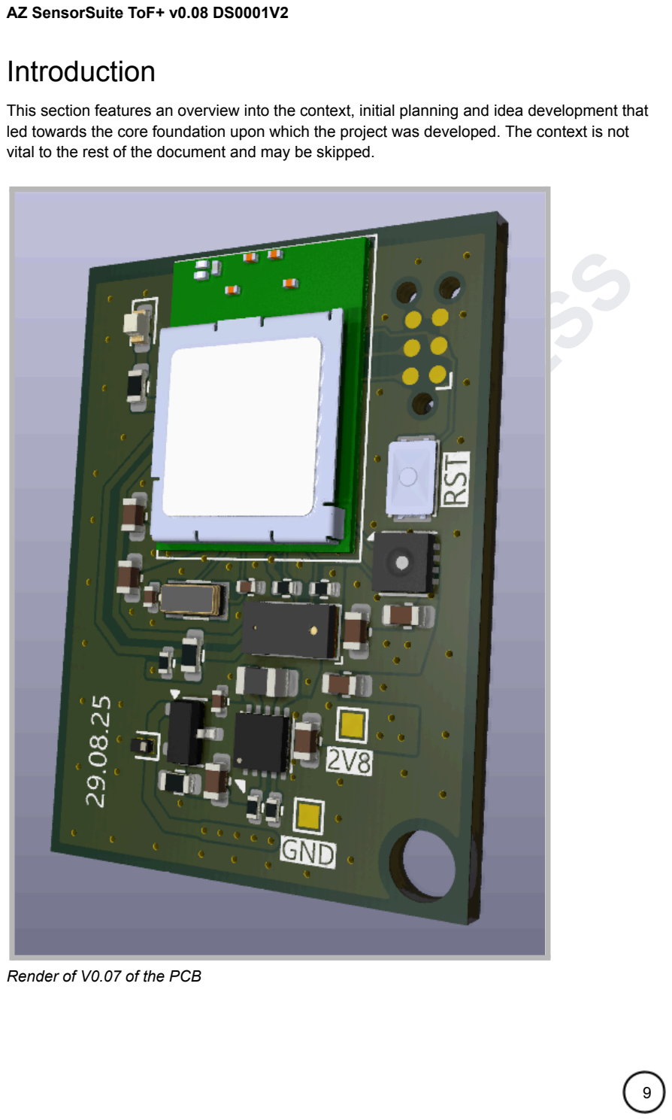
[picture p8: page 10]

# WORK IN PROGRESS

This section features an overview into the context, initial planning and idea development that led towards the core foundation upon which the project was developed. The context is not vital to the rest of the document and may be skipped.

Render of V0.07 of the PCB

# WORK IN PROGRESS

## Context

Many months/years before this project I was taking my GCSE in Technology and Design and was faced with the task of designing a product for my Continuous Assessment. The theme I chose was “Reducing Litter in Schools” and ultimately after not much thought I settled on the bin-object-counter idea. A fairly device that would detect objects falling into a bin and somehow convey the total amount of objects to the user.

Frankly, (even though it scored 39/40 points) it was terrible. It used an IR LED and IR photodiode to detect reflected light. This input would then go to a PIC µC without any processing which would then drive a seven-segment and a buzzer. This concoction was powered by a PP3 (commonly known as 9V) battery going into a L7805CV linear voltage regulator that was probably obsolete 10 years ago

Firstly, in my infinite wisdom I put the IR LED and power LED in series to save current. By some miracle of aliexpress tolerances their forward voltages exceeded 5V and the IR LED wasn’t lighting up fully decreasing the sensing range. By some grace of the gods the PIC accepted the noisy voltage input and the photodiode’s output and drove the seven-segment.

However, you may now start to see one of the main problems of the design. The ~55% efficiency of the linear regulator combined with around 120mA mean current draw to produce an abysmal battery life of 5 hours. A product designed to be used 24/7 for months on end where a single battery costs ~£2 and that was to be installed on every bin in a school. One could say it would “burn money”.

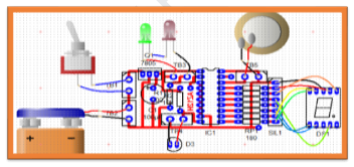
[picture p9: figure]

Highest resolution image of the single layer PCB that I designed. The footprints for the terminal blocks ended up being too small anyway and I had to improvise.

“All my homies hate CircuitWizard” Hans Camenzind* - Inventor of the 555 Timer

Secondly, the casing was no better, an FDM 3D printed main body with acrylic panels stuck and screwed to it. During the assembly of the project several other problems arose. I think it is best if they are laid out in chronological order.

1) The seven-segment is glued in with a surrounding acrylic window.
2) The dupont connectors that were going to connect the seven-segment to the

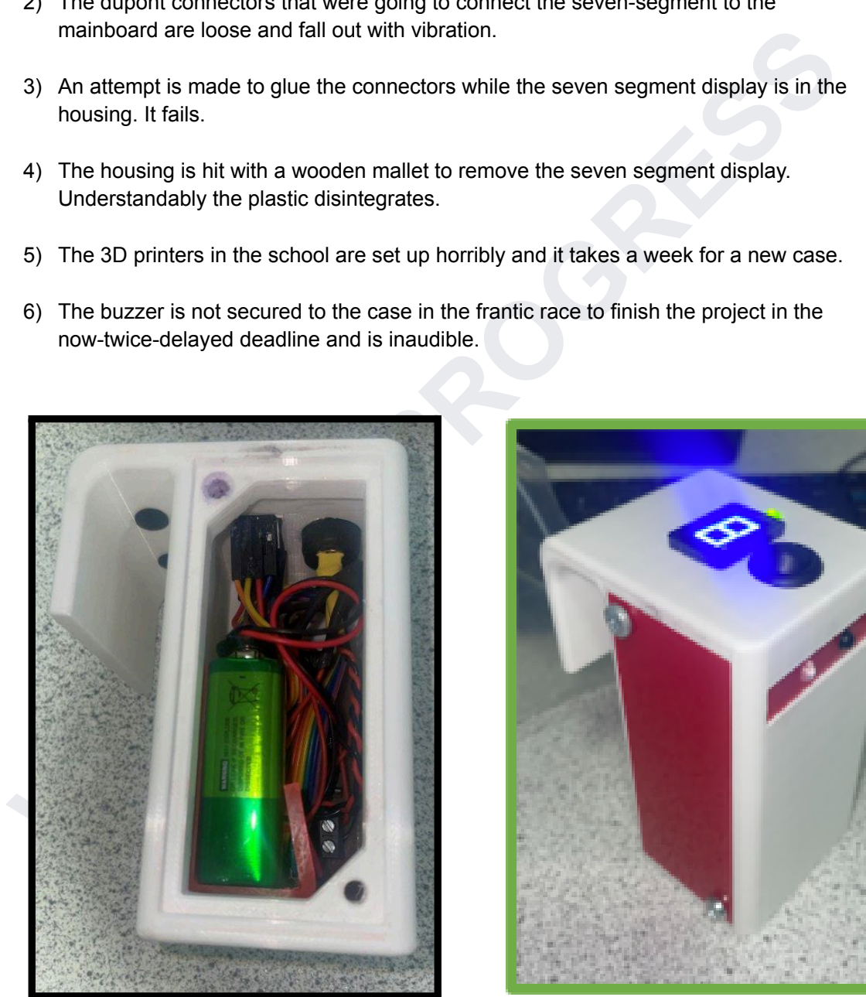
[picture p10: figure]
WORK IN PROGRESS; housing. It fails.

mainboard are loose and fall out with vibration.

3) An attempt is made to glue the connectors while the seven segment display is in the
4) The housing is hit with a wooden mallet to remove the seven segment display. Understandably the plastic disintegrates.
5) The 3D printers in the school are set up horribly and it takes a week for a new case.
6) The buzzer is not secured to the case in the frantic race to finish the project in the now-twice-delayed deadline and is inaudible.

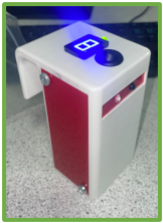
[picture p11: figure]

# WORK IN PROGRESS

You can imagine the nascent kindling of discontent for the design. When I finally finished that project, a yearn for a better version was born that is finally being satisfied. The untapped potential of object detection prompted me to diversify the project. Truthfully, during the design process of the bin sensor project I downloaded KiCAD for the first time and tried to make my own version, but the class had taught me nothing relevant so the idea died off.

Now, after lurking in r/printedcircuitboard and watching an unhealthy amount of lectures and seminars on youtube, I felt ready to design my improved “bin sensor”. The idea popped back into my head when I was sick on holiday in Barcelona (would not recommend), as aforementioned quite a lot of time had passed and my skills had quite substantially increased. Furthermore, a local competition was/is upcoming (I hope) and I wanted to present my updated bin sensor there and hopefully win a prize. This documentation is mainly being made as an effort to compete with the extensive design documents required for GCSE/GCE Continuous Assessment work which makes up a majority of entries.

As such I wanted to expand on the previous project and solve its problems. I was mainly concerned with tackling:

- The horrific battery life
- The lack of data available about the object detection
- The very large form factor
- The singular fixed mounting method
- The large amount of manual assembly

This and more will be discussed in detail in the remainder of this document.

Sincerely,
Adam Zembrzuski 30/08/2025

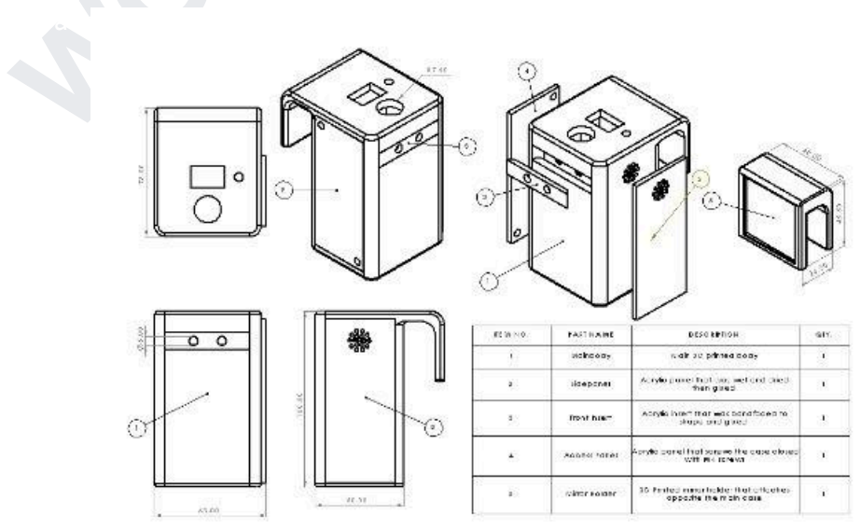
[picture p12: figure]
* (not a real quote)

# WORK IN PROGRESS

## Design Intent and Specification

To create a portable, programmable sensor that can be controlled over BLE and can be deployed in permanent or remote locations. The sensor should output a rich dataset that can be analysed by the end-user to optimise user-specific problems. Such as optimal bin placement or flow control through pathways. The project’s digital interface will be customisable to facilitate custom use cases through a scripting language.

In essence, a competent version of the Bin Sensor.

### ELECTRICAL SPECIFICATION

- Minimum of 1000 hours of active operation with periodic 1Hz measurements on a single battery/charge.
- Responsive BLE interface with less than 100ms of delay
- Minimum 1 metre of detection length in all conditions
- Minimum Bluetooth range of 20m
- Each datapoint should be timestamped with relative time from initialisation
- 95% of pads on one side of PCB
- At least one fault indication output
- 100% Lead Free
- CE and UKCA Conformity

### MECHANICAL SPECIFICATION

- Secure case and mounting methods that deter casual criminals from theft
- Resistance to light rainfall less than 2mm hr

-1
- Drop resistance to 1 metre
- Less than four screws required for assembly
- Smaller than 60x60x20mm
- Cost per kilounit of assembled project below £20000
- Single unit setup in 5 minutes

# WORK IN PROGRESS

# Design Review

Each subsection of the design review will feature decisions split by “class”, decision classes are summarised in the table below.

CLASS NUMBER | IMPORTANCE | EXAMPLE
Class 1 | High Importance | Core design choices or part selection
Class 2 | Medium Importance | Ease of life or functional improvements
Class 3 | Low Importance | Aesthetic or minor adjustments

Class 1 Decision - PCB location in case

Explanation - The strength of the antenna is highly dependent on its surroundings. The case has to be designed around the air gap necessary for the antenna. Adding the air gap later will add unnecessary work and require restructuring.

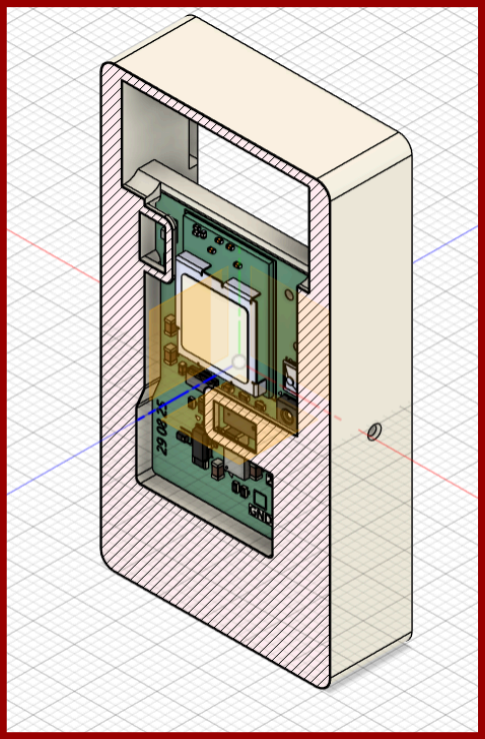
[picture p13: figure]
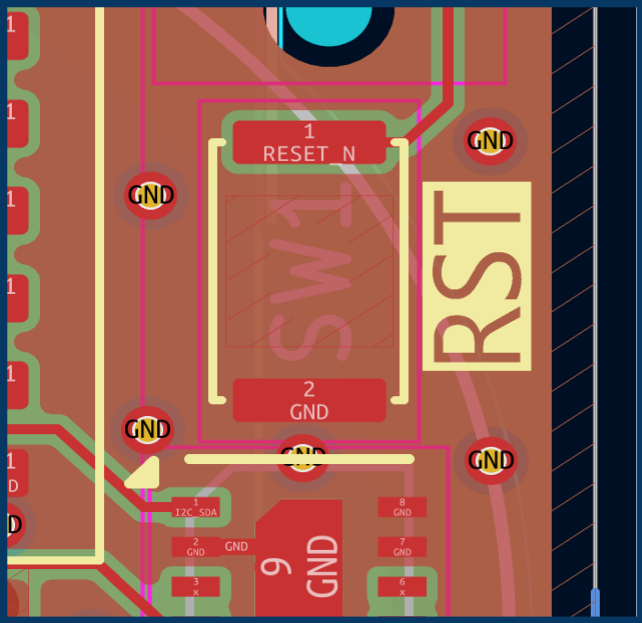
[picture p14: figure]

Class 3 Decision - Silkscreen sizing

Explanation - The silkscreen does not affect the rest of the PCB and does not take priority to any other design-related tasks. It can be done last.

# WORK IN PROGRESS

## Schematic Review

This section contains the class-based review of the relevant schematic and design choices. A full page printed schematic is available at the end of this section.

### CLASS 1

SENSOR SELECTION

The object detection sensor cannot work without an object-detecting sensor. This is why it is at the top of the priority list for the design. An appropriate sensor had to be chosen that would be easy to integrate, very low current and be reasonably cheap. At a first glance, I eliminated IR beams due to their high current. The first option that I considered was the VL53L1X from STMicroelectronics (who will from now on referred to as “ST”).

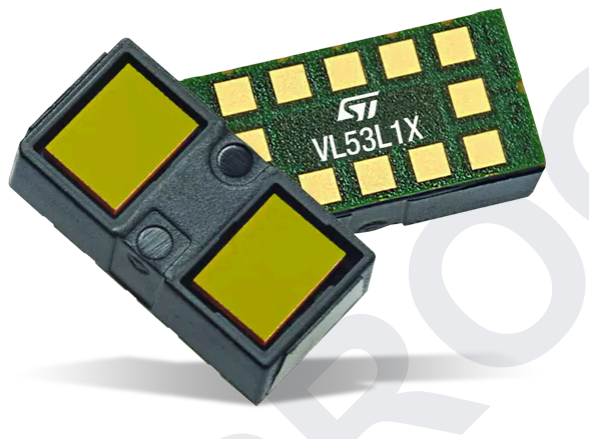
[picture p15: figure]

Image of VL53L1X sensor
Source: ST Microelectronics

This is a state-of-the-art Laser ToF ranging sensor that operates on a single 2V8 input voltage and has a range of up to 4m in long range mode. The minimum ranging distance was also only 1mm with a cost of £2.73 per unit when buying a full reel. So far it ticks all of the specification boxes. It can also be placed behind a transparent PMMA “cover glass” (commonly known as acrylic) to stop water entering the case. So far it ticks all the boxes.

However, if we scroll down to section 6.4 of the datasheet, “Electrical Characteristics” we see a problem. 0.9 to 1.4 mW mean operating power at 1Hz with a 20ms timing budget. This may not seem terrible but it equates to ~500µA. If we assume a battery with 300mAh for simplicity, the sensor alone would run the battery out in 600 hours without any other circuitry. Clearly, this is too much for the 1000 hours of operating time that the product needs. So, I looked to alternatives.

Firstly, I looked at the TDK CH101. This is an ultrasonic ToF sensor that has a much lower power draw than the VL53L1X. It consumes only 15µA at 1Hz with a 1V8 power input. It also features a customisable FoV up to 180° and a range of up to 1.2 metres. It also only requires a single decoupling capacitor and communicates over I

2C. That is where the positives end. Since it uses ultrasound waves it cannot be covered with a cover material meaning that it would be susceptible to liquid damage from outside.

# WORK IN PROGRESS

Furthermore, it requires a plastic “horn” to be fitted onto it to direct the ultrasonic waves which would add to the PCB’s thickness and increase the BOM count. It also requires the use of a proprietary firmware that would increase the software implementation time exponentially. Ultimately, I decided that the wonderful specs on paper were not worth the hassle of integrating it into my design and I continued searching.

Having exhausted my list of usual forums and youtube channels, I turned to ChatGPT to recommend some sensors that I might have overlooked. It was then that I was enlightened about the existence of the VL53L4CD by ST that is very similar to the VL53L1X but has an ultra-low-power firmware that consumes only 55µA at a 2V8 supply. Much more manageable with the current dropping to only 9µA in standby mode. The other specs remained similar, with a 1.2 metre range, single 2V8 supply, I

2C interface and a cost of £1.78 per unit when buying a full reel. It is also pin compatible with the VL53 family of sensors meaning a higher power version can be soldered at any time (with a firmware correction).

The VL53L4CD (and VL53L1X for that matter) are programmed by a C-based API provided by ST. This will allow for the controller to get data from the I

2C interface and allow initial calibration as per ST AN5870 and UM2931. This will allow for a very large range of controllers to be used as the API is in standard C and as I

2C is a very common protocol on embedded ICs.

Next, I wanted to add another sensor to improve the value of the dataset being produced, for this reason I wanted to add a temperature/humidity sensor. Honestly, this thought came to me at the end of the PCB design phase when I realised that there was a redundant 1206 resistor on the board. Removing it made enough space for another sensor IC.

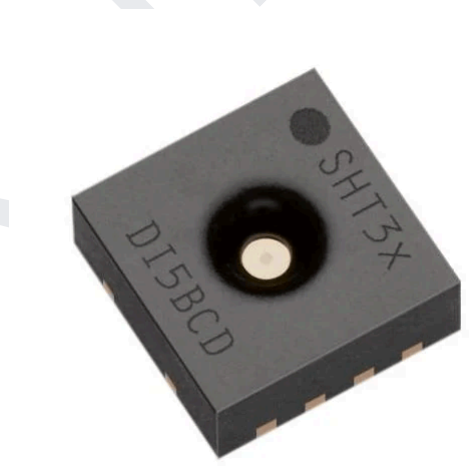
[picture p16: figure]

Render of SHT30 sensor
Source: Sensirion AG

Initially, I wanted to use the SHTC3 by Sensirion AG due to its tiny footprint and ease of implementation, (I

2C and power was all that it needed) however the footprint did not align with my preexisting PCB layout and I did not want to increase the capacitance on the I

2C bus
by adding unnecessary vias (see pg22). For this reason I pivoted to an extremely similar sensor called the SHT30 (also by Sensirion). However with the I

2C pins in different locations so that they fit my PCB layout without vias. The SHT30 has ±2% RH accuracy across 10 to 90% RH and 0.2°C temperature accuracy.

# WORK IN PROGRESS

CONTROL SYSTEM

Let’s look at the specification for a second, the main points that pertain to the control system are - low power, long range Bluetooth communication and an RTC for timekeeping. We must also have a 400KHz capable I

2C interface and at least 2 free GPIO pins for a minimal application. In reality we want at least 10 available GPIO pins in case of future expansion and/or debugging. It would also be preferable to power both the sensor and controller with a single voltage, thus we should look for 2V8 capability.

The first question is how do we plan on doing Bluetooth and achieving an RTC. We can either use separate ICs (µC, BLE transmitter and receiver, RTC) or we can attempt to find a single IC that combines all of these. This IC concept is called a system on chip (SoC) and they are fairly available for common use cases such as portable bluetooth devices so I was able to settle on one fairly quickly.

It was the Nordic NRF54LXX. The two Xs can be either 05,10 or 15 and pertain to the amount of flash memory and RAM that the SoC has. Otherwise they are identical (pin-compatible and all). This SoC is very low power and using Nordic’s OPP for BLE an estimate of 10µA mean current when connected and 30µA when advertising is calculated. The NRF54L15 also incorporates a 2.4GHz radio suitable for BLE 6.0 and an RTC that can wake the SoC on demand (given that the appropriate crystal is connected). It also features many interfaces such as I

2C, SPI, QSPI, USB and many others. As well as having a maximum of 32 GPIO pins.

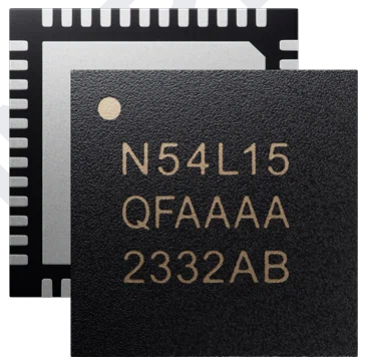
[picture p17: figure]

Image of NRF54L15 in QFN48 (6x6mm) package Source: Nordic Semiconductor

However, the bare SoC does not feature an antenna. This is a problem as creating and tuning an antenna could take months of work and would require certifying the product as an “intentional radiator” which would dramatically increase costs of certification. For this reason, I decided to use a pre-certified module designed with the NRF54L15 and a pretuned PCB antenna. As of the time of development the only module available in stock (due to the newness of the NRF54L15) was the U-Blox Nora B206. It featured a tricky footprint that will be discussed in the PCB review but other than that it was fairly solid. There was also a version with a U.FL connector for external antennas, however I decided against it as I would be limited to a small range of antennas certified with the module and they would all be much larger than the PCB antenna.

# WORK IN PROGRESS

POWER SUPPLY

Ultimately, I had two main power supply options for this project due to the necessary portability and the 2V8 supply. Either, a rechargeable or single-use battery. Lithium polymer and lithium ion rechargeable batteries have become so widespread that their application in hobby-grade projects has become very straightforward. With a Li-Ion battery, a charging IC and a protection IC you already have almost the full implementation. The battery can then be connected by some sort of standard connector (usually JST or molex) et voila, the battery supplies your project.

However, this volatility that allows charging is also a downside, as Li-Ion batteries must be sourced locally as international shipping can be very dangerous due to Li-Ion batteries having the ability to spontaneously combust. This only applies to standard vendors, some sites like AliExpress do offer cheap, Chinese Li-Ion batteries however there is no guarantee of quality.

The idea to use a single-use battery didn’t appear in my head until almost halfway into the project, (at which point I had to redesign all of the power circuitry) as I skipped past single-use batteries as they had similar energy density to Li-Ions and could not be recharged. However, as I was researching other ultra low power devices I saw that most if not all were using some sort of button cell. I questioned myself as to why this was.

I found three main reasons:

1) Single-use batteries are much less volatile than rechargeable batteries and so more easily purchasable.
2) Single-use batteries do not require charging, which takes a lot longer than a simple battery replacement , and necessitates charging circuitry.
3) I could use dedicated coin cell holders soldered onto the PCB to reduce the overall thickness of the product.

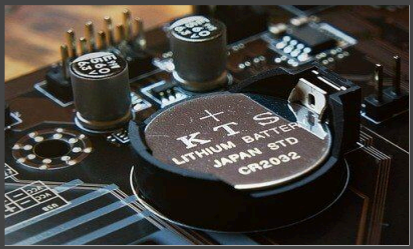
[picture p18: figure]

Image of CR2032 coin cell used in a computer motherboard Source Unknown

However, as with anything in life, there were compromises; the operating voltage range of a 3V nominal CR2032 coin cell is 3V2 to 2V. This range falls above and below the 2V8 system voltage so a more complex voltage regulation arrangement had to be used.

Fig. 1 shows the continuous discharge characteristics of an Energizer CR2032 battery. Notice how the voltage is above 2V8 for most of the lifecycle and then falls below for approximately the last quarter.

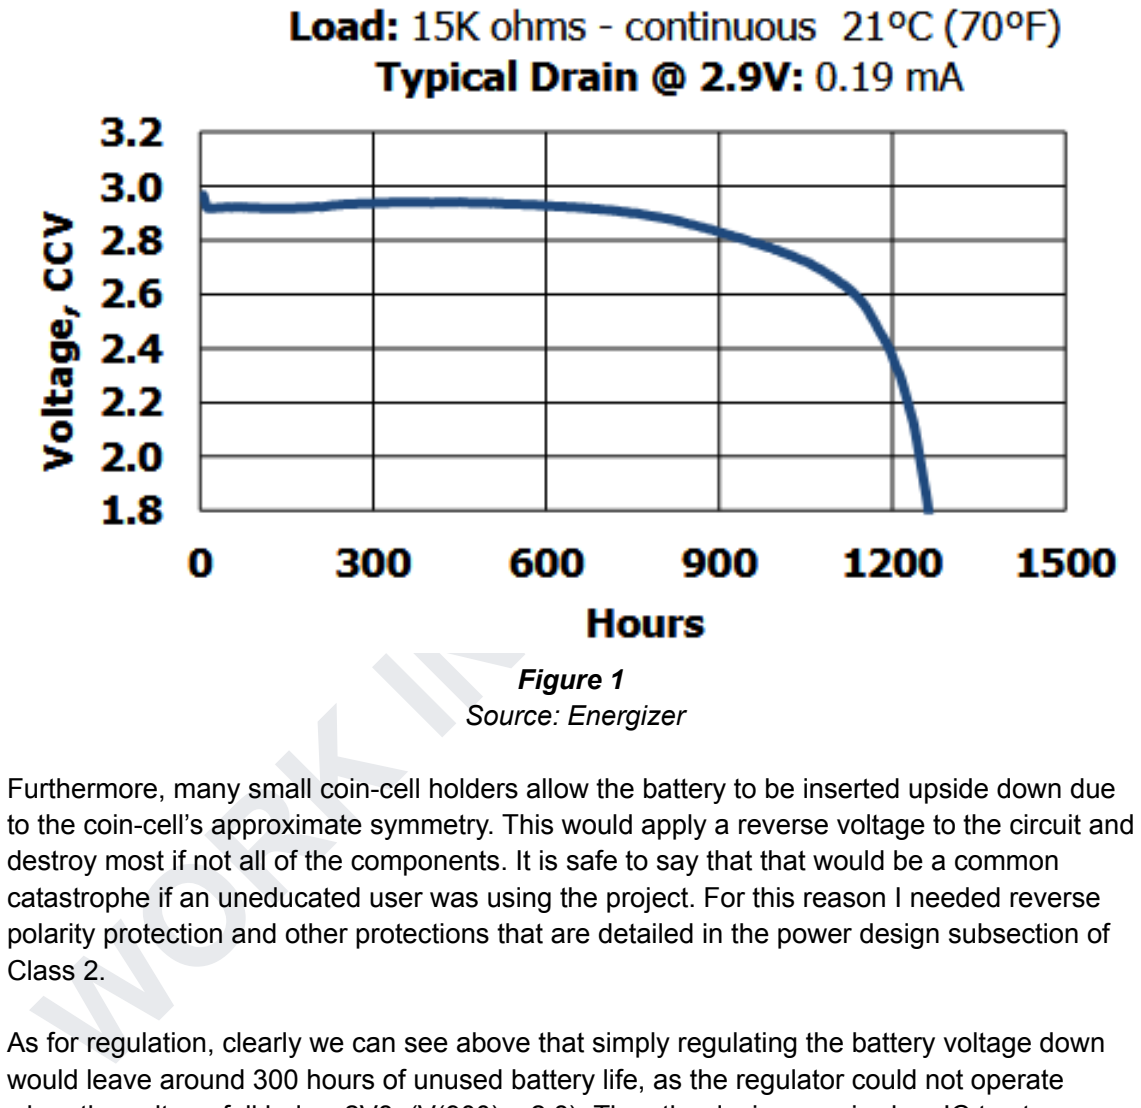
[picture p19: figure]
WORK IN PROGRESS; Figure 1 Source: Energizer; Class 2.

Furthermore, many small coin-cell holders allow the battery to be inserted upside down due to the coin-cell’s approximate symmetry. This would apply a reverse voltage to the circuit and destroy most if not all of the components. It is safe to say that that would be a common catastrophe if an uneducated user was using the project. For this reason I needed reverse polarity protection and other protections that are detailed in the power design subsection of

As for regulation, clearly we can see above that simply regulating the battery voltage down would leave around 300 hours of unused battery life, as the regulator could not operate when the voltage fell below 2V8, (V(900) ≈ 2.8). Thus the design required an IC to step voltages both down and up as required. The SMPS topology that I decided to use was buck-boost. This is due to the fact that it requires very little supporting circuitry relative to something like a SEPIC topology supply. My buck boost design only required a single inductor as opposed to two in a SEPIC supply. More information on IC selection is in the power design subsection of Class 2.

# WORK IN PROGRESS

### CLASS 2

NORA B206 INTEGRATION

Integrating the Nora B206 was one of the first tasks that I completed in this project as it was a simple case of drawing some symbols and footprints, and adding some simple external components. As my EDA tool did not have a symbol for the fairly new Nora B2 module family, I had to draw my own symbol. I placed all of the GPIO pins without alternate peripheral assignments (not including ADC inputs) on the left side of the symbol, and all of the pins with alternate peripherals on the right side. As per usual power pins were on the top and ground pins on the bottom. This allowed me to maintain a clean and very legible schematic.

The footprint for the Nora B206 was the first LGA footprint that I had ever made, so it took me a bit of time to figure out the grid snap controls and pad sizing. I also had to implement the keep out zone for the antenna to keep as much of its performance as possible. More info on the design of the antenna surroundings is in the PCB review section. After an initial struggle and an hour or two of staring at the datasheet the footprint was finished.

Following that, I could move on to placing the passive components for operation and some additional debugging components. Firstly, the decoupling capacitors C5 and C6 were added as per the suggestion of the Nora B206 datasheet. I aimed for at least 10V, X7R capacitors throughout the whole project to reduce DC bias and maintain a roughly constant capacitance across a large temperature range.

Furthermore, for accurate RTC operation I decided to add an external 32.768KHz crystal that would provide the clock for the RTC system. I picked the SC32S-7PF20PPM manufactured by Seiko Instruments as it has a low load capacitance that slightly reduces the overall power consumption, low tolerance of 20PPM and comes in a small package. The load capacitors had to be calculated by the formula C
L = (C
1

* C
2

)/(C

1 + C
2

) + C
Stray
which simplified to 14 − 2C | . CStray was measured physically to be xpF and the final
stray = C
load capacitors were xpF.

For programming and general debugging, I opted to add a Tag Connect TC2030NL programming header that would connect to the debug output of the Nordic NRF54L15 Development Kit. This would allow me to use the Segger J-Link OB to debug the SoC without having to solder any wires or use permanent connectors. Mass programming also becomes much faster as the TC2030 uses pogo pins to connect to the target. I also added a PTM button to enable the user to reset the system as there is no power switch.

Finally, I added a low current LED that will turn on when a fault is detected to notify the user of a problem, prompting a system reset. The fault will also be broadcast in the bluetooth communications. The LED will also be used during development for various development purposes such as checking that processes are working. The LED output is also connected to a test pad; the GPIO’s output will actually be data sent at 10KHz so that it is legible by
human inspection on an oscilloscope or similar without affecting visibility.

# WORK IN PROGRESS

SENSOR INTEGRATION

Continuing from the last section, here I will discuss the integration of the selected sensor (VL53L4CD and SHT31) and the I

2C bus. Both sensors accept 2V8 as their operating voltage so they are both powered from the main power supply. This “engineered simplicity” of having a single power supply greatly cleans the schematic and will help with the PCB routing. As per before, both sensors require minimal decoupling capacitors, a 4.7µF and 0.1µF for the VL53L4CD and a 0.1µF for the SHT31.

As for specifics, the VL53L4CD features the pins “GPIO1” and “XSHUT” which are used for power saving in the SoC. Namely, GPIO1 goes low to alert the SoC when data is ready to be read, which wakes the SoC and initiates many I

2C reads via the api. Whereas, XSHUT is driven by the SoC and can put the VL53L4CD in or out of standby mode by driving the pin low or high respectively. Both GPIO1 and XSHUT must be driven at all times for proper operation, so 1M pull up resistors are used to keep the signal high when possible.

1M pull up resistors are used as a compromise between pull up strength and current draw; as smaller resistors would have more noise immunity and allow faster rise times (due to the parasitic capacitance an RC delay is formed), however they would take more current. The two 1M resistors draw a constant 3.4µA which helps to lengthen the battery life. These large resistances are starting to push at the edge of usable noise however due to the low speed nature of the signals and with some careful PCB design we can ensure stable operation.

Similarly, the SHT31 features two additional pins, NRESET and ALERT. As the name suggests NRESET is an active low reset. There is an internal pull up resistor so it can be left floating. ALERT can be configured to send an interrupt when a condition is achieved such as temperature surpassing a set point, this works similarly to the GPIO1 pin of the VL53L4CD however as the SHT31 will be used in one-shot mode this is irrelevant.

One-shot mode is the mode where a single measurement is taken and then the sensor goes back to sleep. Here is a very simplified flow diagram of the B206’s logic.

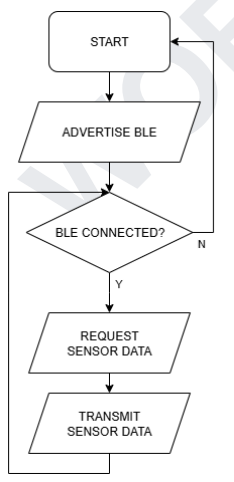
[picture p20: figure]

Importantly, upon requesting the data, the SoC goes into System Idle mode, and wakes up based on the GPIO1 pin going low on the VL53L4CD so as to not waste battery life. Furthermore, due to the long measurement time of the SHT31, the B206 requests readings on one cycle but then only sends them during a later cycle, as a humidity reading takes up to 8 seconds and a temperature reading takes up to 2 seconds.

The SHT31 readings should never take precedence over constant VL53L4CD readings so that the object detection is uninterrupted.

# WORK IN PROGRESS

I also optimised the I

2C pull up resistors similarly to what was required for the 32.768KHz crystal’s load capacitors. Due to the high frequency of the I

2C bus (100KHz to 1MHz), signal rise times become a very prominent matter when choosing pull-up resistor values. The parasitic/stray capacitances of the controller, pcb traces and each device add up to form an RC delay which delays the signal as the “capacitor” created by the stray capacitance (dis)charges. This meant that I had to measure the capacitance of the PCB and then use a calculator to calculate the maximum allowed resistors for my application. For a standard mode (100KHz), I

2C signal, the rise time must be below 1000nS (1µS). This meant that for my 40pF of capacitance at 2V8 I could have up to 28K resistors.

However, this would prove unnecessary as after finishing the design of the PCB I realised that it would be more efficient to simply disconnect the pull-ups when the I

2C bus was not in
use. This would result in much lower mean current meaning more of the power budget could be dedicated to the ICs.

This meant that I would either 1) have to add mosfets as low side switches to disable the resistors when required (obviously connected to GPIO) or 2) use the NRF54L15’s internal configurable pullups. I chose to use the NRF54L15’s internal pullups as I did not want to add to the BOM and truthfully I did not have enough space on the PCB for even the smallest of SMD transistors and I did not want to do a PCB (and consequently) case redesign. Albeit, the internal pull ups on the NRF54L15 are only 13K meaning that power consumption could be reduced in a new revision.

POWER DESIGN

At the start of most of my power designs I navigate to Texas Instruments’ WEBENCH online tool. WEBENCH is a very powerful tool that works by having you enter some key specs (Input voltage range, output voltage, load current etc.) and then presenting you with power solutions filtered by efficiency, cost, footprint area, etc. The image below is my whole input, which generated a list of suitable ICs. The TPS63900 was the most efficient non-BGA design which is mainly why I chose it. (I do not have BGA soldering capabilities)

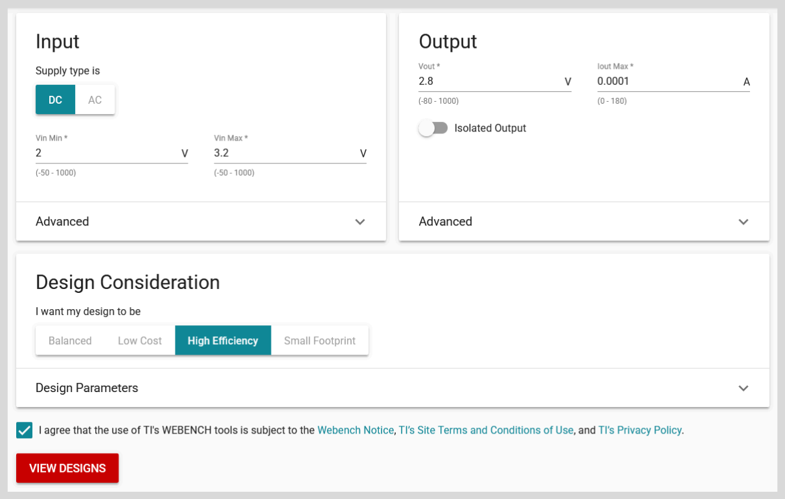
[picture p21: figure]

# WORK IN PROGRESS

By using the datasheet implementation of the IC, I was bypassing 80% of the research required to make an efficient power implementation. WEBENCH stated that ideally my design would work at 88.6% efficiency when boosting from 2V to 2V8 and at 92.6% in buck mode. This is helped by the fact that the TPS63900 boasts an insanely low 75nA quiescent current.

I measured peak inductor current on the PCB to select an inductor with the appropriate saturation current; however the project’s production has seen delays as I am waiting for a confirmation of my Arkwright Scholarship in early September so that I can use the funds provided. As a placeholder I selected a low DCR inductor with saturation current similar to what is in the recommended inductors section of the datasheet. (AOTA-B201210S2R2MT)

It was also necessary to use a 13.3K resistor to set the output voltage, and I added an optional 1.87K resistor to limit the input current to 25mA so as to not exceed the maximum pulse current capacity of the CR2032. The soft-start capability of the TPS63900 also helps to not surpass this peak current on initial battery connection.

Furthermore, the TPS63900 integrates output short-circuit and overtemperature protection, which greatly increases the safety of the device in the case of a fault. As aforementioned I also had to implement reverse voltage protection to protect against the battery being inserted upside down. The two approaches that I considered were, using a zener diode in series with the battery, using a P Channel MOSFET (PMOS). The zener diode approach is the simplest as it involves just a single part, however the diode has a voltage drop which would dissipate energy as heat. Additionally, the battery output voltage would be lower leading to lower buck-boost efficiency.

On the contrary, we can use a PMOS as a high side switch that operates with a very low resistance. The battery +ve is connected to the drain and the output is connected to the source, then the gate is connected to ground. I also placed an optional large resistor (4M7) between gate and source to prevent the gate from floating and disrupting operation.

The basis of using a PMOS as reverse voltage protection is this. A PMOS requires a negative voltage difference, V to conduct. Otherwise the PMOS conducts through the body
GS
diode which is inefficient due to the voltage drop. However, when a +ve voltage is applied, the source becomes almost the drain voltage as current passes through the forward biased body diode, making V lower (above the minimum threshold) and enhancing the PMOS so
GS
that it can conduct with its low resistance (RDS | .
ON | )

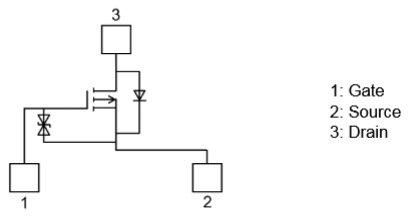
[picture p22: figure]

# WORK IN PROGRESS

Pin assignment of SSM3J338R Source: Toshiba

If a -ve voltage is applied, only minimal leakage current can go through from drain to source as the body diode becomes reverse biased. The PMOS does not enhance as the V
GS
becomes +ve whereas it needs to be -ve. For example, the PMOS that I chose (SSM3J338R,LF) has a V of -1.8V meaning that I need to apply at least that to the source
GS
for the PMOS to conduct. When the PMOS starts conducting the resistance is only ~20mOhms meaning that a very minimal voltage drop occurs. Theoretically we can maintain 99.97% efficiency.

Another form of protection that I implemented was a TVS diode for transients generated from ESD events. A TVS diode is a zener diode designed with the intent of clamping voltage spikes to a low level. The diode is reverse biased and when a voltage greater than the zener breakdown voltage appears at the battery +ve, the TVS diode rapidly opens a path to ground to absorb the energy of the ESD event instead of it going through the circuit. Even walking across a carpet can create an ESD event near 10kV.

The TVS diode must be carefully chosen for its reverse breakdown voltage (V ), i.e. the RWM voltage below which the diode will not conduct significantly, its clamping voltage (VC), the maximum voltage that appears across the diode in a transient event and the reverse leakage current, the current that can leak through the diode in reverse bias. With that in mind I chose the AQ1250-01ETG, which has a VWM of 5V (much more than out theoretical 3V2 max, a VC of 8.7V which our PFET and voltage regulator can tolerate, and finally an ultra low quiescent current of 20nA which will barely affect battery longevity.

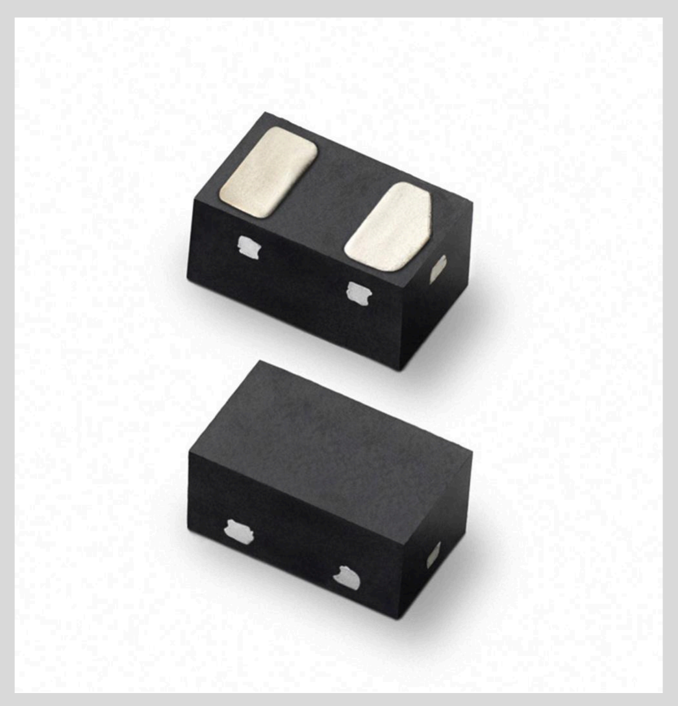
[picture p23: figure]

Image of AQ1250-01ETG in SOD-882 package (1 x 0.6mm) Source: Littelfuse

# WORK IN PROGRESS

### CLASS 3

Ultimately, most of the design work for the schematic must be done with a lot of care and consideration as it is the backbone for the rest of the design; for this reason Classes 3 will have less writing in this schematic review section. Expect more in the following reviews.

GENERAL IMPROVEMENTS

In order to save a few nA, I only used port 1 GPIO on the Nora B206 as it means that only that port has to be enabled. Port 1 also has interrupt and wake up capabilities unlike port 2. Port 0 was unsuitable as it only has 4 or 5 exposed pins depending on the package.

Another improvement I made was removing a resistor that I planned to solder on after programming. It was an NRESET pullup however as per the Nora B2 System Integration Manual there is already an internal pullup on the NRESET meaning an additional pull up would only waste current and space.

Penultimately, I added a few status LEDs and relevant test points so that when the first prototype inevitably didn’t work I could pinpoint why faster. It was also important to place ground test points near all data test points to reduce parasitics in order to produce a truer representation of the signals on an oscilloscope.

The last functional improvement that I made was adding 2V8 and ground test points, the battery voltage can be measured by directly probing the holder. I did not place test points on the I

2C traces as the stubs would add capacitance which would then reduce the maximum pull up resistance and increase current as mentioned earlier.

For the final note of this section I will talk about the aesthetic and legibility improvements to the schematic. Firstly, I ordered the designator numbers by their position in the schematic -the schematic should be read in the order ->

1) POWER
2) SoC
3) DEBUG
4) SENSORS

I also added bounding boxes around each subsection to make the schematic clearer. I also applied general schematic design rules throughout the entire design such as power symbols facing up, ground symbols facing down, and no four way junctions of wires. I also used appropriately named labels for all important signals and power.

As promised before, the full schematic is on the page below

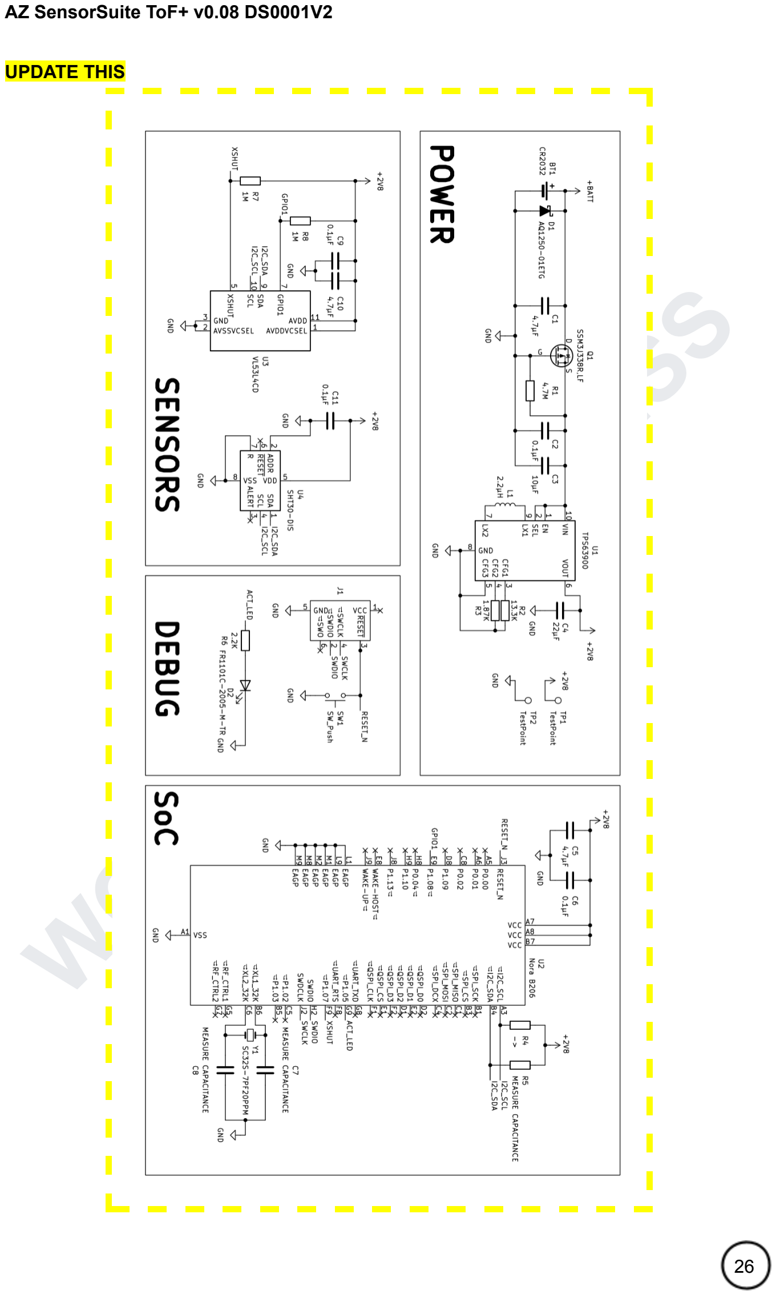
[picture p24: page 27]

# WORK IN PROGRESS

UPDATE THIS

# WORK IN PROGRESS

## PCB Review

This section contains the class-based review of the pcb design including but not limited to, part placement, signal integrity and package selection. The front and rear copper layers are available at the end of the section.

### CLASS 1

PCB FABRICATION SPECIFICATIONS

For better understanding of the following sections, it is a good idea to discuss the fab specifications for the PCB. This includes the number of layers (and physical stackup), surface finish/material, via covering method et cetera. As a sidenote, I decided to assemble the PCB myself to reduce costs and to be able to use component distributors with European warehouses that stocked the relatively new Nora B2x6 modules.

Initially, after the first layout, it was obvious to me that I should use a four layer board. Power routing on a two layer board increased routing complexity significantly and having dedicated ground planes on a four layer board would improve signal integrity. I ended up with the following electrical stackup:

Layer 1 - Signal
Layer 2 - Ground
Layer 3 - Power (2V8)
Layer 4 - Ground

Layer 1 was where all of the signal routing took place, it was also surrounded with a ground pour for copper balance and improved noise immunity/signal integrity. Squeezing as much immunity to noise as possible into the PCB was imperative so that the weak GPIO pull up resistors could function. Layer 2 was an uninterrupted ground plane. Importantly it is the next layer from the signal which brings similar effects as the ground pour on Layer 1. All ground layers were stitched with vias to ensure ground integrity. Similarly, Layer 3 carried all of the power. Layer 4, was in majority a ground plane with the exception of a short trace carrying the battery positive a short distance. In practice this ground is not used much and the trace was quite short so the EMC implications are negligible.


ENIG (left) vs HASL (right) aesthetic appearance

# WORK IN PROGRESS

As detailed in the next section, the surface finish and and via covering were heavily dependent on the battery retainer. Firstly, a 2µ” ENIG (Electroless Nickel Immersion Gold) surface finish was chosen for its increased durability, excellent surface planarity (which improves fine pitch soldering reliability), increased corrosion resistance and for the fact that it is lead-free. As opposed to a single layer of SnPb (or alternatives) in HASL, ENIG involves a layer of electroless nickel and a very thin layer of immersion gold (0.05 to 0.1 µm). The design also required tented vias so that power vias did not contact against the battery negative and cause a short-circuit fault.

PACKAGE SELECTION

Firstly, the size of the PCB was constrained by the battery holder (and battery) size plus the antenna keepout zone. The PCB size was going to be heavily based off of the battery holder size so I had to choose a small holder. There were two main options, battery retainers and battery holders.

A battery retainer contacts against only one side of the battery (CR2032 cells have a positive contact on one side and a negative on the other), where the PCB requires exposed conductor (commonly some type of gold). Ideally hard gold would be selectively electroplated onto just the battery contact pad however this would drastically increase costs unless manufacturing in bulk. For this reason ENIG is the preferred finish for low-volume prototypes.

In contrast, battery holders generally contact both sides of the battery meaning the battery doesn’t physically touch the PCB. This improves connection reliability, almost nullifies the risk of long term failure from repeated abrasion on the battery contact pad meaning that more expensive surface finishes such as ENIG are not strictly required.

Battery holders, however, are usually a few millimeters longer than holders due to being more than a single piece of shaped metal. Thus I chose to use the Keystone 3034 retainer as I already had a footprint for it and it was readily available at major distributors such as Digikey.

As for major IC package selection, I was constrained to the footprint of each particular IC. If I needed a specific feature, it was rather unlikely that I could find an IC with a different footprint but with the same features. For example, the Nora B206 is the only available NRF54Lxx module available in large quantities as of writing (13/09/25) meaning I must put up with its very dense LGA package. Similarly, ST only manufactures their ToF sensor range in LGA however all of the pads are on the perimeter of the package meaning routing is straightforward. The SMPS IC also only had a single footprint (non LGA/BGA).

However, due to the late nature of the addition of the temp/humidity sensor, the pinout/package was very important. Look at Figure 2 below, showing the I

2C traces leaving
the SoC. The I

2C traces going downwards are going to the ToF and are not to be changed, the temp sensor is to the right. Visibly, the data trace is above the clock trace. (I

2C
development will be discussed in detail in the software review).

This meant I had to find an IC with its data and clock pins in the same orientation, otherwise I would have to cross them. I did not want to cross them as I would have to use vias which would add unnecessary capacitance (see pg15) or use zero ohm resistors which would add to the BoM. This meant that I did not use the first temp sensor that I found (which was the SHTC3), that offered a slightly smaller package and slightly better package but its larger cousin, the SHT30.

WORK IN PROGRESS; Figure 2

As for passives, the minimum package that I set was 0402 (Imperial, equivalent to 1005 metric). This was the smallest size that I felt I could put onto the board with tweezers so that it could be soldered by hotplate. Advantages of small packages include cheaper prices and increased component density potential. However, small packages usually mean worse power handling and thermal performance. Small packaged MLCCs can also struggle to achieve large capacitances with decent specs.

For this reason, I tried to use 0605 components whenever possible unless 0402 made a significant space saving or small loop area was required (eg in the SMPS). Notably I used an 0805 inductor instead of a larger power inductor as due to the orientation of the buck-boost IC (discussed in the next section) it would extend the board length by a noticeable amount.

Furthermore, the DCR increase was manageable,112mOhms in the 0805 vs ~60mOhms in a power inductor. The difference at the (expected) low current is negligible as other factors will dominate power consumption however I plan to use this IC and inductor combination in other projects where it may make a significant difference.

CORE LAYOUT

The approximate layout of major components was the first step of the design of the actual PCB. I had a lot of flexibility at this stage as there were only two main constraints, the SoC’s antenna had to be on the edge of the board, and the board could not be smaller than the battery holder (duh).

Quite surprisingly, my initial layout worked very well. In Figure 3 below, red lines represent top layer components and blue lines represent bottom layer components. The temperature

WORK IN PROGRESS; Figure 3; minimum PCB size. This meant that the major IC placements could be optimised for routing instead of board size which greatly improved the ease of development.; The SoC was the first component I placed as the antenna has to be on the edge of the board and be away from tall components. It served as the reference for where all of the other components should be.; out zone of the antenna. As to minimise the perimeter size of the board.; Then, I added the ToF sensor. The I; 2C pads on the ToF

sensor is dashed as it was not present at the start of the layout design.

Evidently, the battery holder dictates the

I then placed the battery as far upwards as possible without overlapping the keep

2C pads of the NORA B206 are located near the bottom right (looking down on the copper on the pcb) so that it aligned with the I
sensor. The ToF sensor was placed very close to the SoC so that the trace length could be minimised, reducing stray capacitance and improving noise immunity. The ToF is slightly offset to the right so that the 32.768KHz crystal could be accommodated.

Finally, the SMPS was placed next to one of the battery +ve pads (as visible in green in Fig. 3). This was so that I could minimise the distance from the +ve to the SMPS Vin

to
reduce ohmic losses and voltage drop as an effect of increased resistance. The shorter connection also minimised parasitic inductance which helps to reduce noise and improves efficiency.

### CLASS 2

SMPS LAYOUT

Power supply layout was a key task in order to achieve high efficiency thereby extending battery life. Below, Figure 4 displays the power supply layout. In the middle we see the heart of the power supply, the TPS63900 buck boost converter. The layout revolves around this IC so it is imperative that it is placed and orientated efficiently. In this configuration, the 2V8

WORK IN PROGRESS use of vias.; Figure 4; transistor.

output is close to the ICs that require it above and all connections can be made without the

Components not relevant to the power supply have been marked by white boxes.

However, let's talk about the layout sequentially, from battery to 2V8 output. First, a cluster of five vias connects the +ve terminal of the battery holder to the PMOS responsible for RPP. The net is labeled +BATT. Before +BATT reaches the PMOS however, there is the aforementioned ESD diode (visible on the very left of the image). It is closer to the battery than the transistor so that ESD events are clamped through it instead of destroying the

Next, the net Q1-S connects to all relevant pads via a large ground pour. This is a common theme in this design and serves to reduce ohmic losses and voltage drop by decreasing resistance, and to reduce noise by reducing parasitic inductance. The two config resistors appear at the bottom of the layout, above the +BATT via cluster. As I had the space I placed them very close to the IC however their placement is not crucial and they could be fairly far away on the board if necessary (within reason).

# WORK IN PROGRESS

Notice how all of the capacitors are very close to the main IC with many ground vias for return current. This is to reduce the loop inductance, minimising noise and EMI. Furthermore, as the capacitors get further and further away from the IC, the impedance of the PDN increases, and their ability to attenuate electrical noise decreases, causing a worse output with more noise. This is due to the return loop getting larger. In a similar fashion, if the capacitors are close to the IC but the ground path is long, the PDN impedance increases and the design suffers. Similar principles apply to the connection of the inductor, although it obviously is not used for noise purposes but to complete the buck boost topology.

Lastly, the power supply connects to the power (2V8) plane with a via cluster to the right side. The three vias reduce the resistance that the current sees reducing ohmic losses and voltage drop. Next to it, there is a test point to test (using a DMM or similar) if 2V8 is actually produced. The ground reference is below, near the config resistors. They are both marked by silkscreen.

NOISE IMMUNITY AND SIGNAL INTEGRITY PART 1

PROGRAMMING

LGA FAN OUT

RF DESIGN

Being conscious of RF performance was necessary throughout the entirety of the PCB design phase. Bad antenna layout would mean reduced range (due to the worse antenna performance) and increased power consumption (due to more retransmissions due to lost data).

### CLASS 3

SILKSCREEN

MINIATURIZATION

COMPONENT SPECIFIC REQS

SIGNAL INTEGRITY PART 2

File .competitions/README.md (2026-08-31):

# Competitions

This folder is for storing AZSensorSuite competition entries and their supporting documentation.

Each competition should have its own subfolder containing the submitted entry (write-ups, photos, videos, presentation files, etc.) along with any notes on the results or feedback received.

> [!NOTE]
> This folder does not affect the build of the hardware, firmware, or software in this repository. It exists purely as an archive/record of where AZSensorSuite has been entered or showcased.

## Structure

Layout for each entry:

```
.competitions/
└── <competition-name>/
    ├── README.md        # Summary of the entry, category, and outcome
    ├── entry/           # Submitted materials (docs, slides, media, etc.)
    └── media/           # Supporting photos/videos, if not included above
```

## Entries

| Competition | Month | Year | Status | Notes |
|---|---|---|---|---|
| IoE National Electronics Competition | 08 | 2026 | Waiting for result | |
| Sentinus Young Innovators | 09 | 2026 | Preparing entry | |

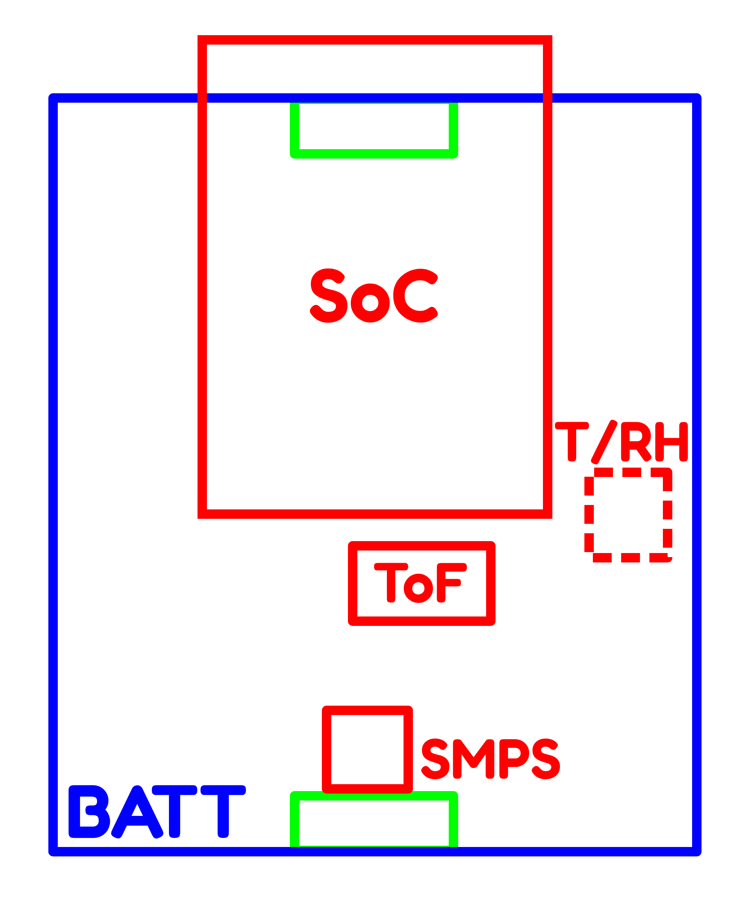
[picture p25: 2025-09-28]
GH_UPLOAD/DIAGRAMS/coarse layout.png

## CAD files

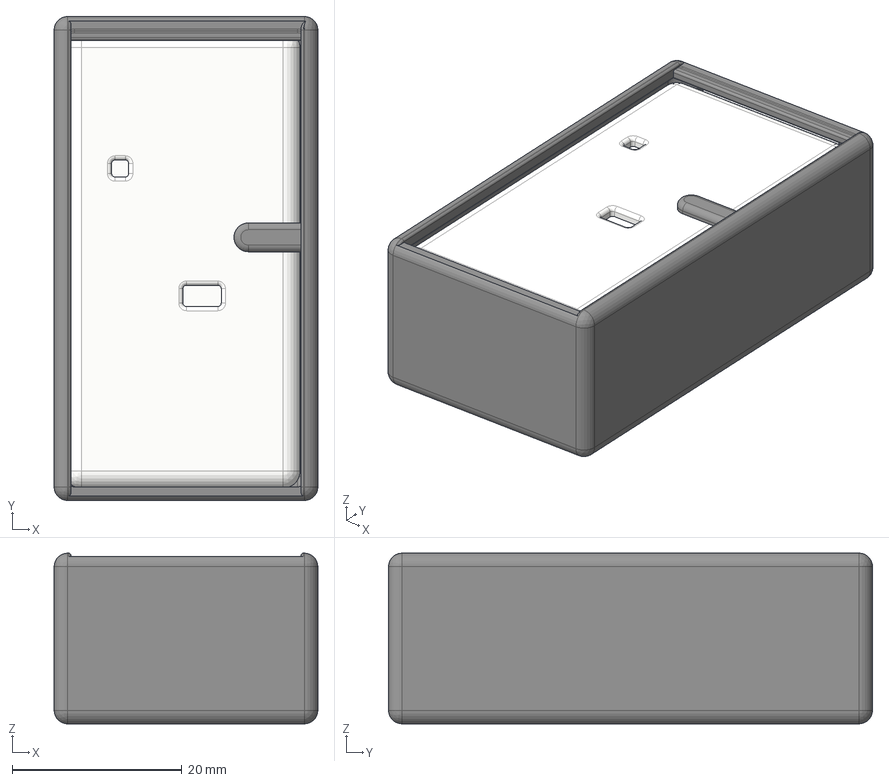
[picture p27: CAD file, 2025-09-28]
GH_UPLOAD/STEP_V72/COMPLETE.step
31.1 x 57.0 x 20.1 mm
FRONT_CASE
WINDOW x 2
BACK_CASE
SHOCK_ABSORBER
DIN 7984 - M3 x 5 Steel 4.6 Plain
R_0402_1005Metric x 5
LED_0603_1608Metric x 3
C_0603_1608Metric x 8
v0-11 1.7.1
Crystal_SMD_3215-2Pin_3.2x1.5mm
C_0402_1005Metric x 3
R_0603_1608Metric x 5
D_SOD-882D
SOT-23
NORA-B106-00B_NORA-B106-00B
L_0805_2012Metric
VL53L0CXV0DH1--3DModel-STEP-418109
SHT30-DIS-B
BatteryHolder_Keystone_3034_1x20mm
azss_PCB

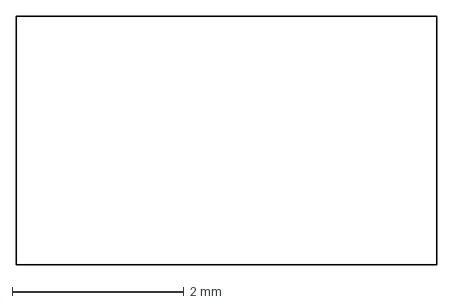
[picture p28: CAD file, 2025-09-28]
GH_UPLOAD/DXF/WINDOW.dxf
4.90 x 2.90 mm

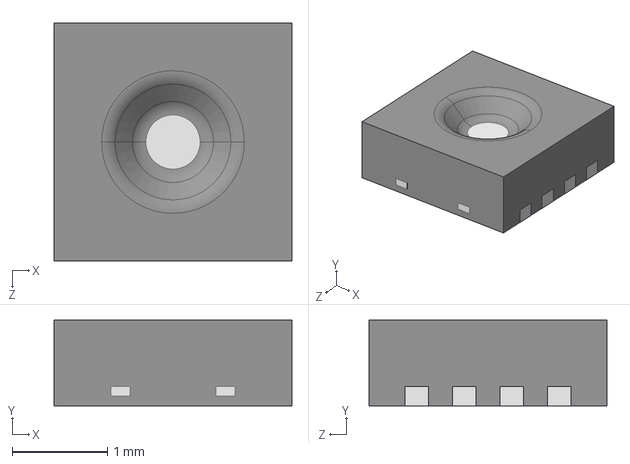
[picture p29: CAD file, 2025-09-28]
GH_UPLOAD/EXT_MODELS/SHT30-DIS-B.STEP
2.50 x 0.901 x 2.50 mm

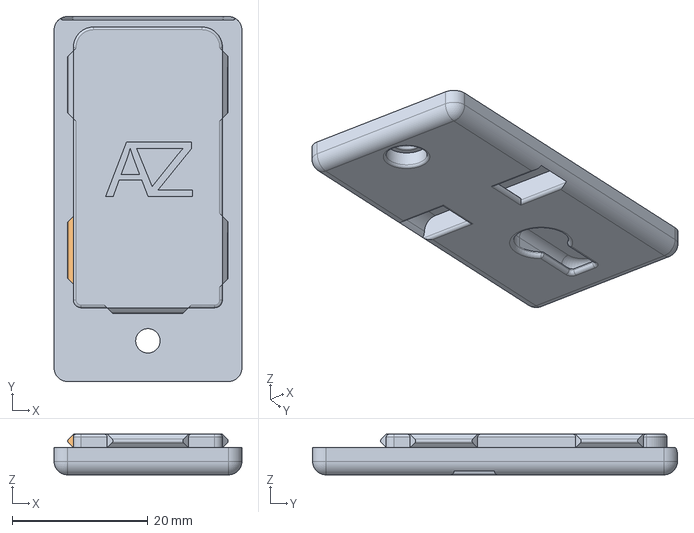
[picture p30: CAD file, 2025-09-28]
GH_UPLOAD/STEP_V72/BACK_CASE.step
27.7 x 53.9 x 6.00 mm

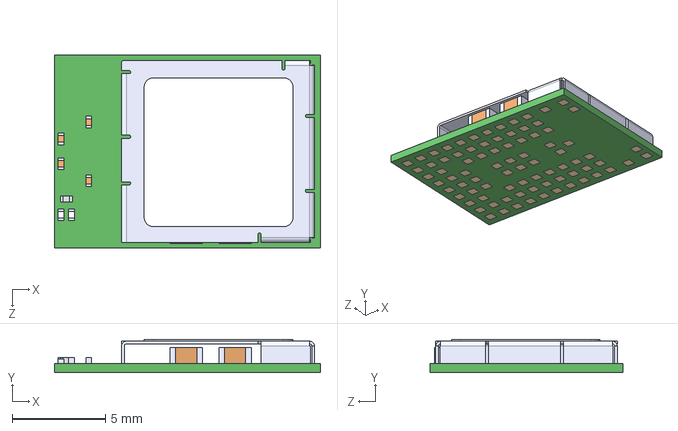
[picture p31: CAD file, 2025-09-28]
GH_UPLOAD/EXT_MODELS/NORA-B106-00B--3DModel-STEP-510211.STEP
14.3 x 1.80 x 10.4 mm

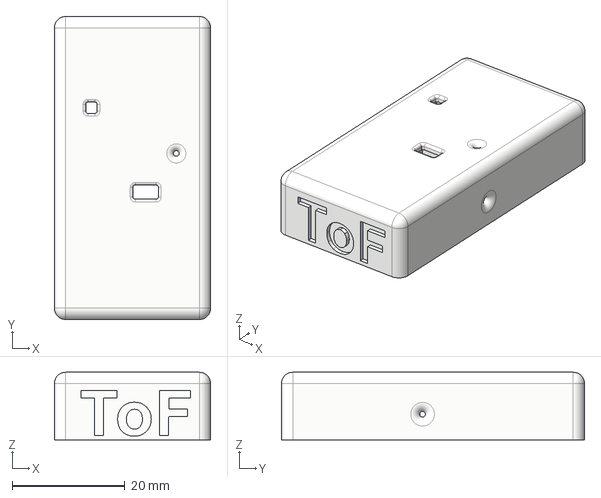
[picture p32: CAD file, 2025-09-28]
GH_UPLOAD/STEP_V72/FRONT_CASE.step
27.8 x 53.9 x 12.0 mm

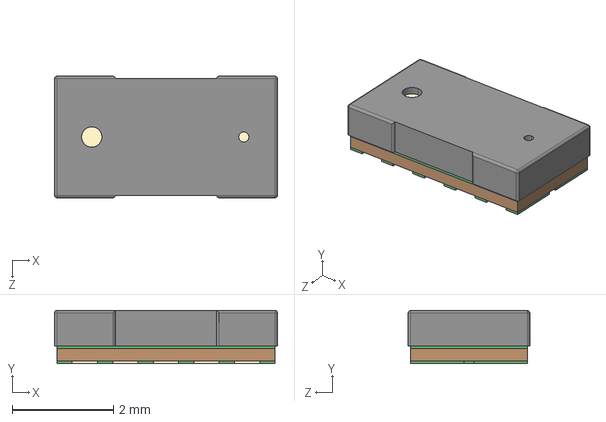
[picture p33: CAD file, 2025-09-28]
GH_UPLOAD/EXT_MODELS/VL53L0CXV0DH1--3DModel-STEP-418109.STEP
4.40 x 1.05 x 2.40 mm

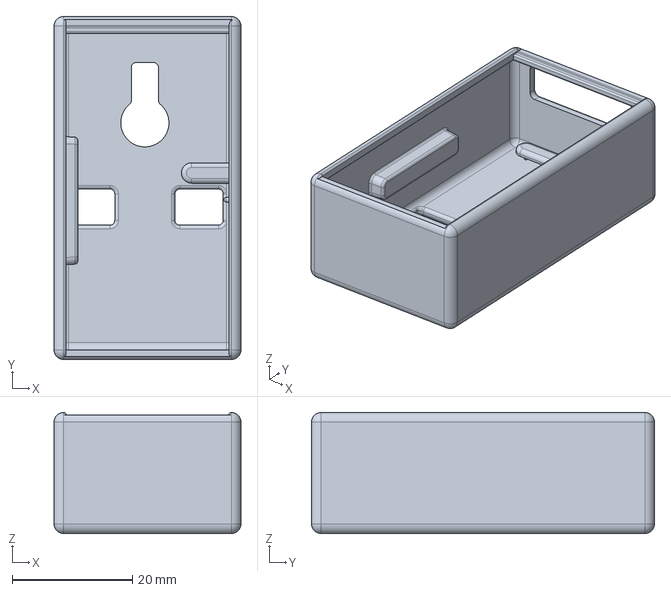
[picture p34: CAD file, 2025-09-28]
GH_UPLOAD/STEP_V72/SHOCK_ABSORBER.step
31.1 x 57.0 x 20.1 mm

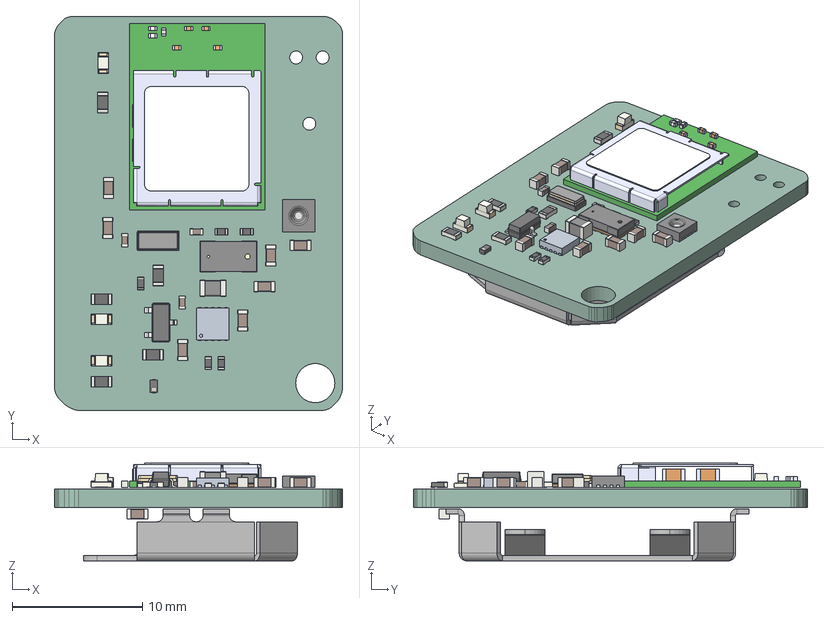
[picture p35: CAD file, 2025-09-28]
GH_UPLOAD/STEP_V72/PCB V0-11.step
22.1 x 30.2 x 7.50 mm
R_0402_1005Metric x 5
LED_0603_1608Metric x 3
C_0603_1608Metric x 8
v0-11 1.7.1
Crystal_SMD_3215-2Pin_3.2x1.5mm
C_0402_1005Metric x 3
R_0603_1608Metric x 5
D_SOD-882D
SOT-23
NORA-B106-00B_NORA-B106-00B
L_0805_2012Metric
VL53L0CXV0DH1--3DModel-STEP-418109
SHT30-DIS-B
BatteryHolder_Keystone_3034_1x20mm
azss_PCB

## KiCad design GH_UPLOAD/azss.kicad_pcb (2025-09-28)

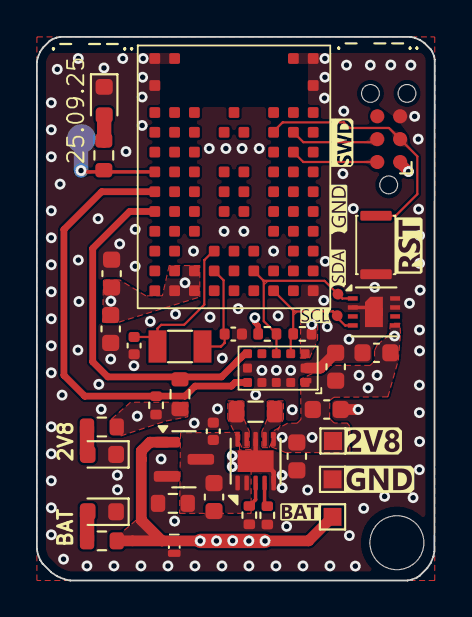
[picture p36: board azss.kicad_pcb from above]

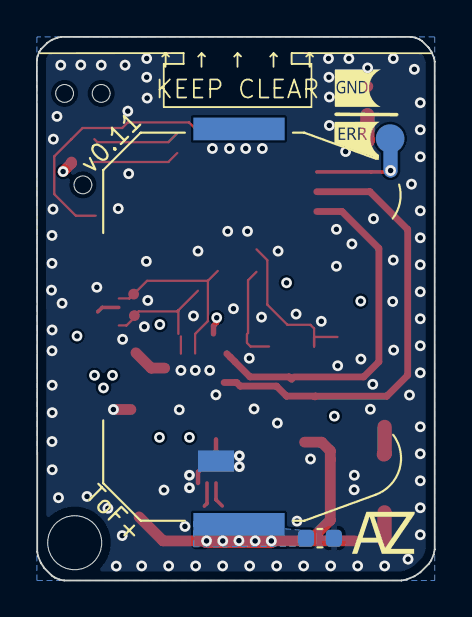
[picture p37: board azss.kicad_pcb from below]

Board: 4 copper layers, 22.1 x 30.2 mm, 38 parts (2 on the bottom side), 21 nets.

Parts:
BT1: CR2032; BatteryHolder_Keystone_3034_1x20mm
C1, C5, C10: 4.7µF; C_0603_1608Metric
C2: 0.1µF; C_0402_1005Metric
C3: 10µF; C_0603_1608Metric
C4: 22µF; C_0603_1608Metric
C6, C9, C11: 0.1µF; C_0603_1608Metric
C7, C8: MEASURE CAPACITANCE; C_0402_1005Metric
D1: AQ1250-01ETG; D_SOD-882_DFN1006-2_TVS
D2: FR1101C-2005-M-TR; LED_0603_1608Metric
D3, D4: LED; LED_0603_1608Metric
J1: Conn_ARM_SWD_TagConnect_TC2030; Tag-Connect_TC2030-IDC-NL_2x03_P1.27mm_Vertical
L1: 2.2µH; L_0805_2012Metric
Q1: SSM3J338R,LF; SOT-23
R1: 4.7M; R_0603_1608Metric
R2: 13.3K; R_0402_1005Metric
R3: 1.87K; R_0402_1005Metric
R4, R5: 4.7K; R_0402_1005Metric
R6, R9, R10: 2.2K; R_0603_1608Metric
R7: 2M; R_0402_1005Metric
R8: 2M; R_0603_1608Metric
SW1: SW_Push; EVP-AWCD4A
TP1, TP2, TP5: TestPoint; TestPoint_Pad_1.0x1.0mm
U1: TPS63900; WSON-10-1EP_2.5x2.5mm_P0.5mm_EP1.2x2mm_ThermalVias
U2: Nora B206; Nora B2x6
U3: VL53L4CD
U4: SHT30-DIS; Sensirion_DFN-8-1EP_2.5x2.5mm_P0.5mm_EP1.1x1.7mm
Y1: SC32S-7PF20PPM; Crystal_SMD_3215-2Pin_3.2x1.5mm

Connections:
+2V8: C4.1, C5.1, C6.1, C9.1, C10.1, C11.1, J1.1 (VCC), R4.1, R5.1, R7.1, R8.1, R10.1, TP1.1, U1.6 (VOUT), U2.A7 (VCC), U2.A8 (VCC), U2.B7 (VCC), U3.1 (AVDDVCSEL), U3.11 (AVDD), U4.5 (VDD)
+BATT: BT1.1 (+), C1.1, D1.2 (K), Q1.1 (D), R9.1, TP5.1
/ERROR_OUT: R6.2, U2.G9 (P1.05)
/GPIO1: R8.2, U2.E9 (P1.08), U3.7 (GPIO1)
/I2C_SCL: R4.2, U2.A3 (I2C_SCL), U3.10 (SCL), U4.4 (SCL)
/I2C_SDA: R5.2, U2.B4 (I2C_SDA), U3.9 (SDA), U4.1 (SDA)
/RESET_N: J1.3 (~RESET), SW1.1, U2.J3 (RESET_N)
/SWCLK: J1.4 (SWCLK), U2.J2 (SWDCLK)
/SWDIO: J1.2 (SWDIO), U2.H2 (SWDIO)
/XSHUT: R7.2, U2.F9 (P1.07), U3.5 (XSHUT)
GND: BT1.2 (-), C1.2, C2.2, C3.2, C4.2, C5.2, C6.2, C7.2, C8.2, C9.2, C10.2, C11.2, D1.1 (A), D2.1 (K), D3.1 (K), D4.1 (K), J1.5 (GND), Q1.2 (G), R1.1, R2.2, R3.2, SW1.2, TP2.1, U1.5 (CFG3), U1.8 (GND), U1.11 (GND), U2.A1 (VSS), U2.L1 (EAGP), U2.L9 (EAGP), U2.M1 (EAGP), U2.M2 (EAGP), U2.M8 (EAGP), U2.M9 (EAGP), U3.2 (AVSSVCSEL), U3.3 (GND), U3.4 (GND), U3.6 (GND), U3.12 (GND), U4.2 (ADDR), U4.7 (R), U4.8 (VSS), U4.9 (VSS)
unnamed: D2.2 (A), R6.1
unnamed: D3.2 (A), R9.2
unnamed: D4.2 (A), R10.2
unnamed: C2.1, C3.1, Q1.3 (S), R1.2, U1.1 (EN), U1.2 (SEL), U1.10 (VIN)
unnamed: R2.1, U1.3 (CFG1)
unnamed: R3.1, U1.4 (CFG2)
unnamed: L1.2, U1.9 (LX1)
unnamed: L1.1, U1.7 (LX2)
unnamed: C7.1, U2.B6 (XL1_32K), Y1.1
unnamed: C8.1, U2.C6 (XL2_32K), Y1.2

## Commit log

2025-09-28 relevant final design files uploaded
    [BACK_CASE.step, COMPLETE.step, FRONT_CASE.step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]
2026-07-30 Update readme with sponsorship and PCB details
    Added sponsorship acknowledgment and updated PCB specifications.
2026-07-30 Add PCB Ordering Guide to README
    Added a PCB ordering guide sponsored by PCBWay to the README.
2026-07-30 Revise README for firmware and order review details
    Updated the README to reflect changes in example firmware functionality and added a note about PCBWay's order review time.
2026-08-28 Update README with PCBWay sponsorship and wording changes
    Added sponsorship badge for PCBWay and improved wording in the PCB Ordering Guide section.
2026-09-06 Update firmware compatibility to PCB V1.12

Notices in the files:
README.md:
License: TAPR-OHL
